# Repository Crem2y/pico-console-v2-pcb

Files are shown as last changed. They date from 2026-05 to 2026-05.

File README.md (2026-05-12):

# Pico console V2 Board
- Tool : Kicad 9.0
# schematics
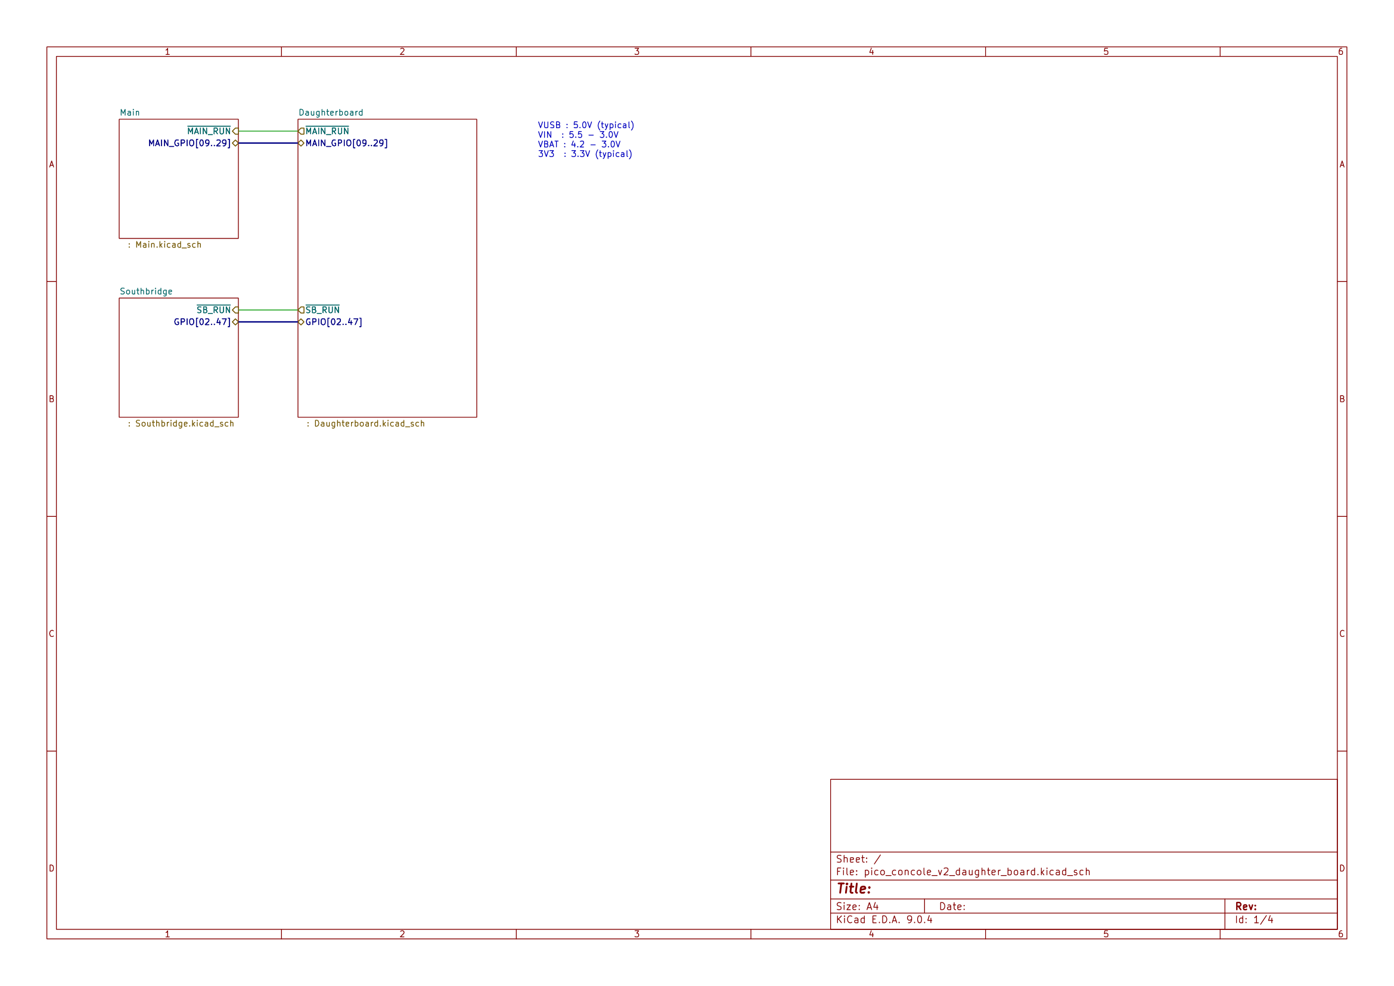
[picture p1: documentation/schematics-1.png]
schematics-1

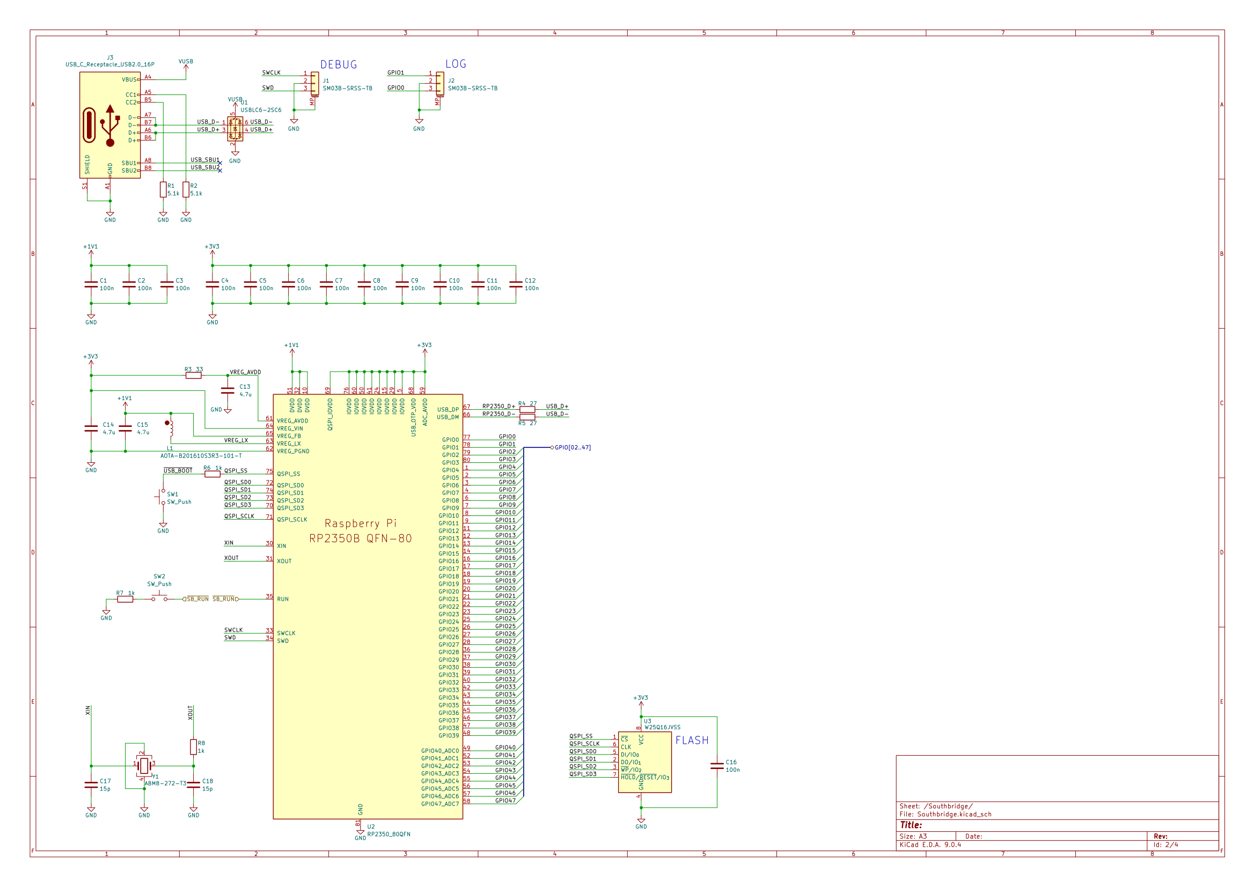
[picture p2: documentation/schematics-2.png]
schematics-2

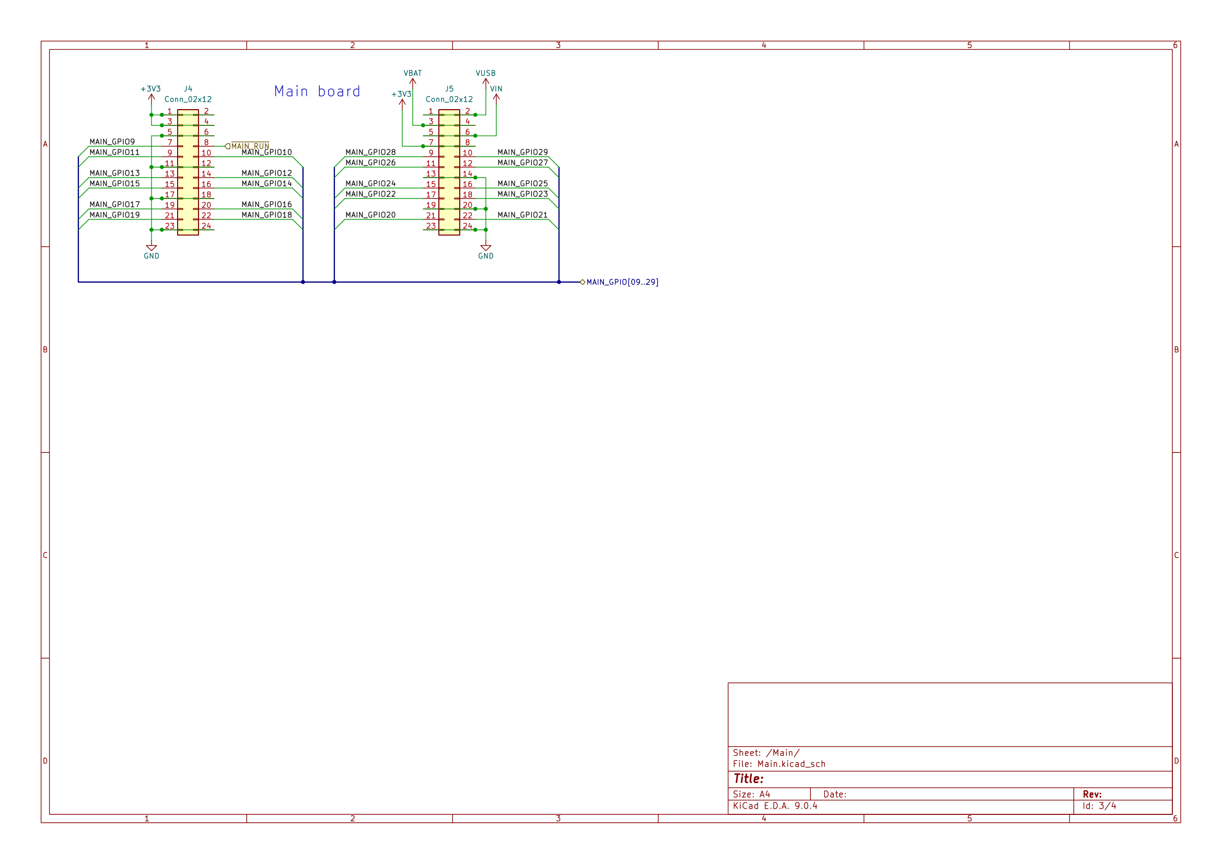
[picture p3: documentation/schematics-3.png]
schematics-3

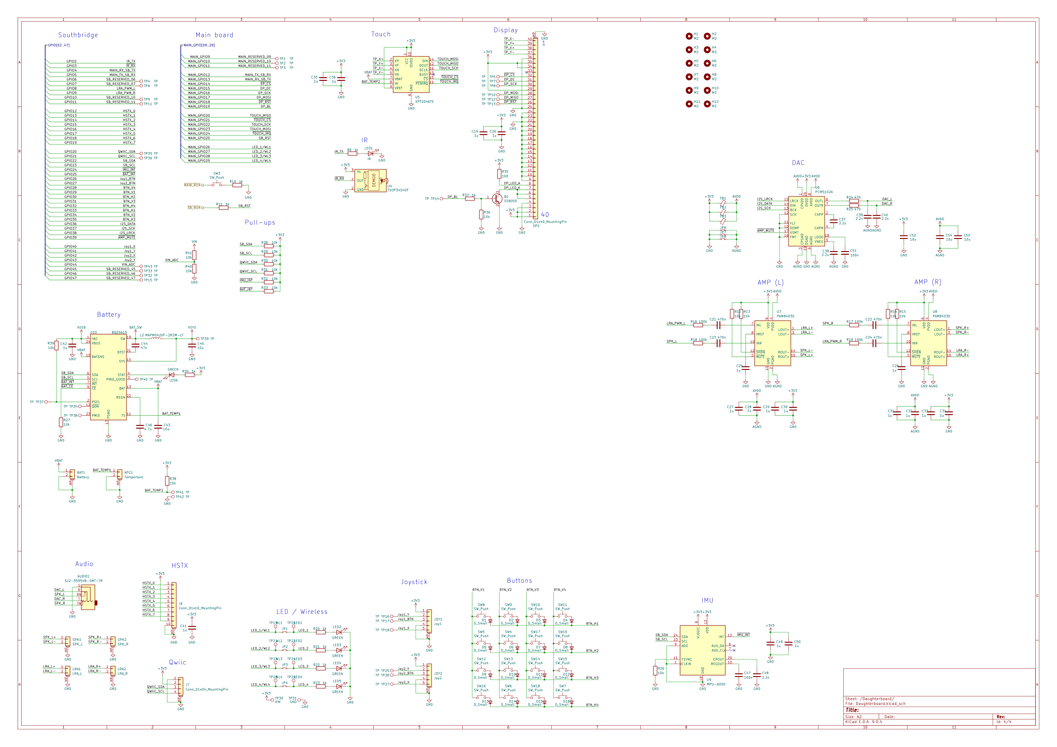
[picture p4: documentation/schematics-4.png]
schematics-4

# PCB
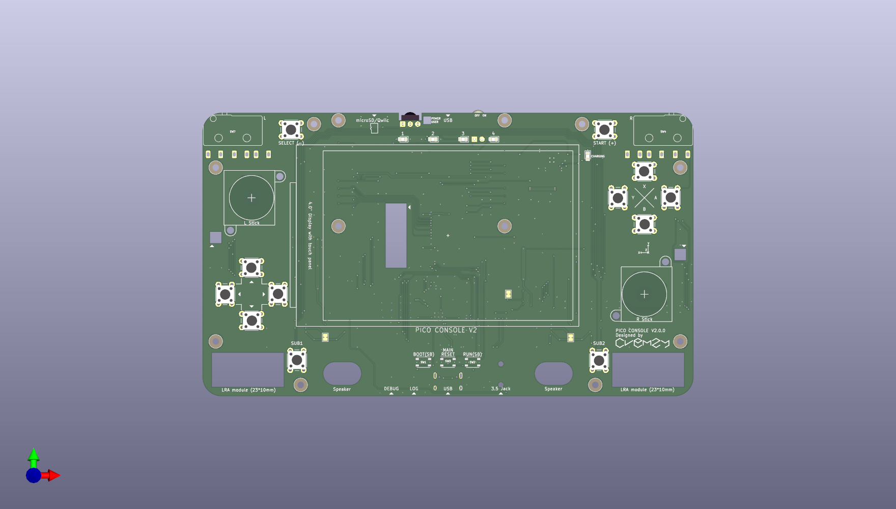
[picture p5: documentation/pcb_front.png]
pcb_front

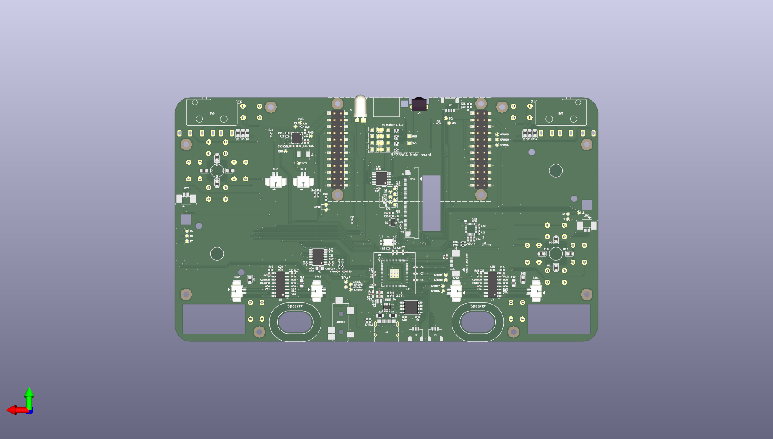
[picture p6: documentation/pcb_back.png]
pcb_back


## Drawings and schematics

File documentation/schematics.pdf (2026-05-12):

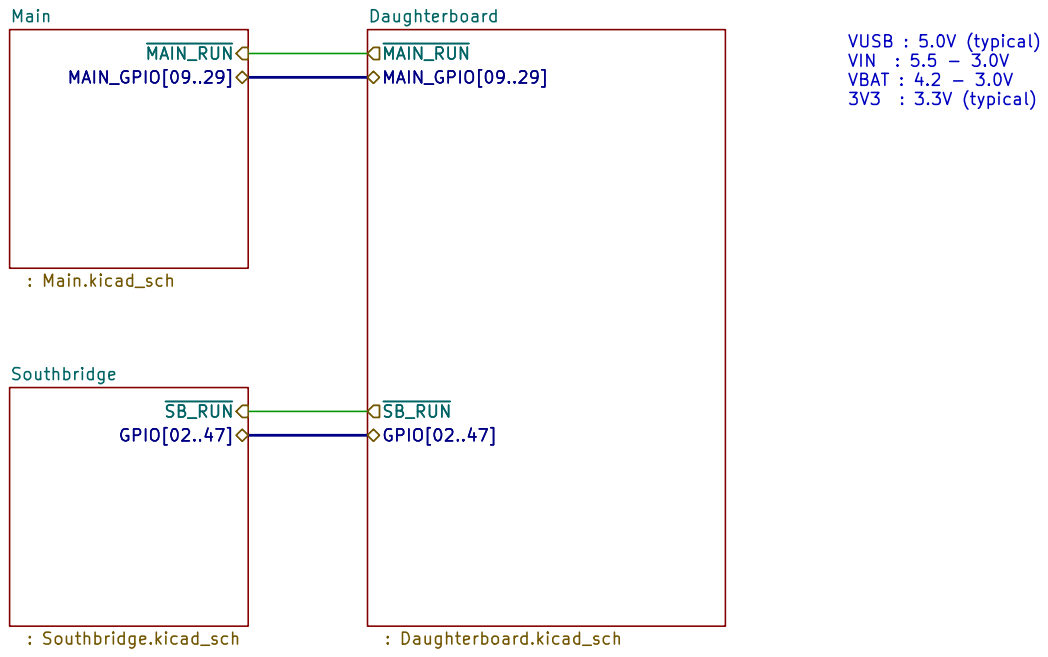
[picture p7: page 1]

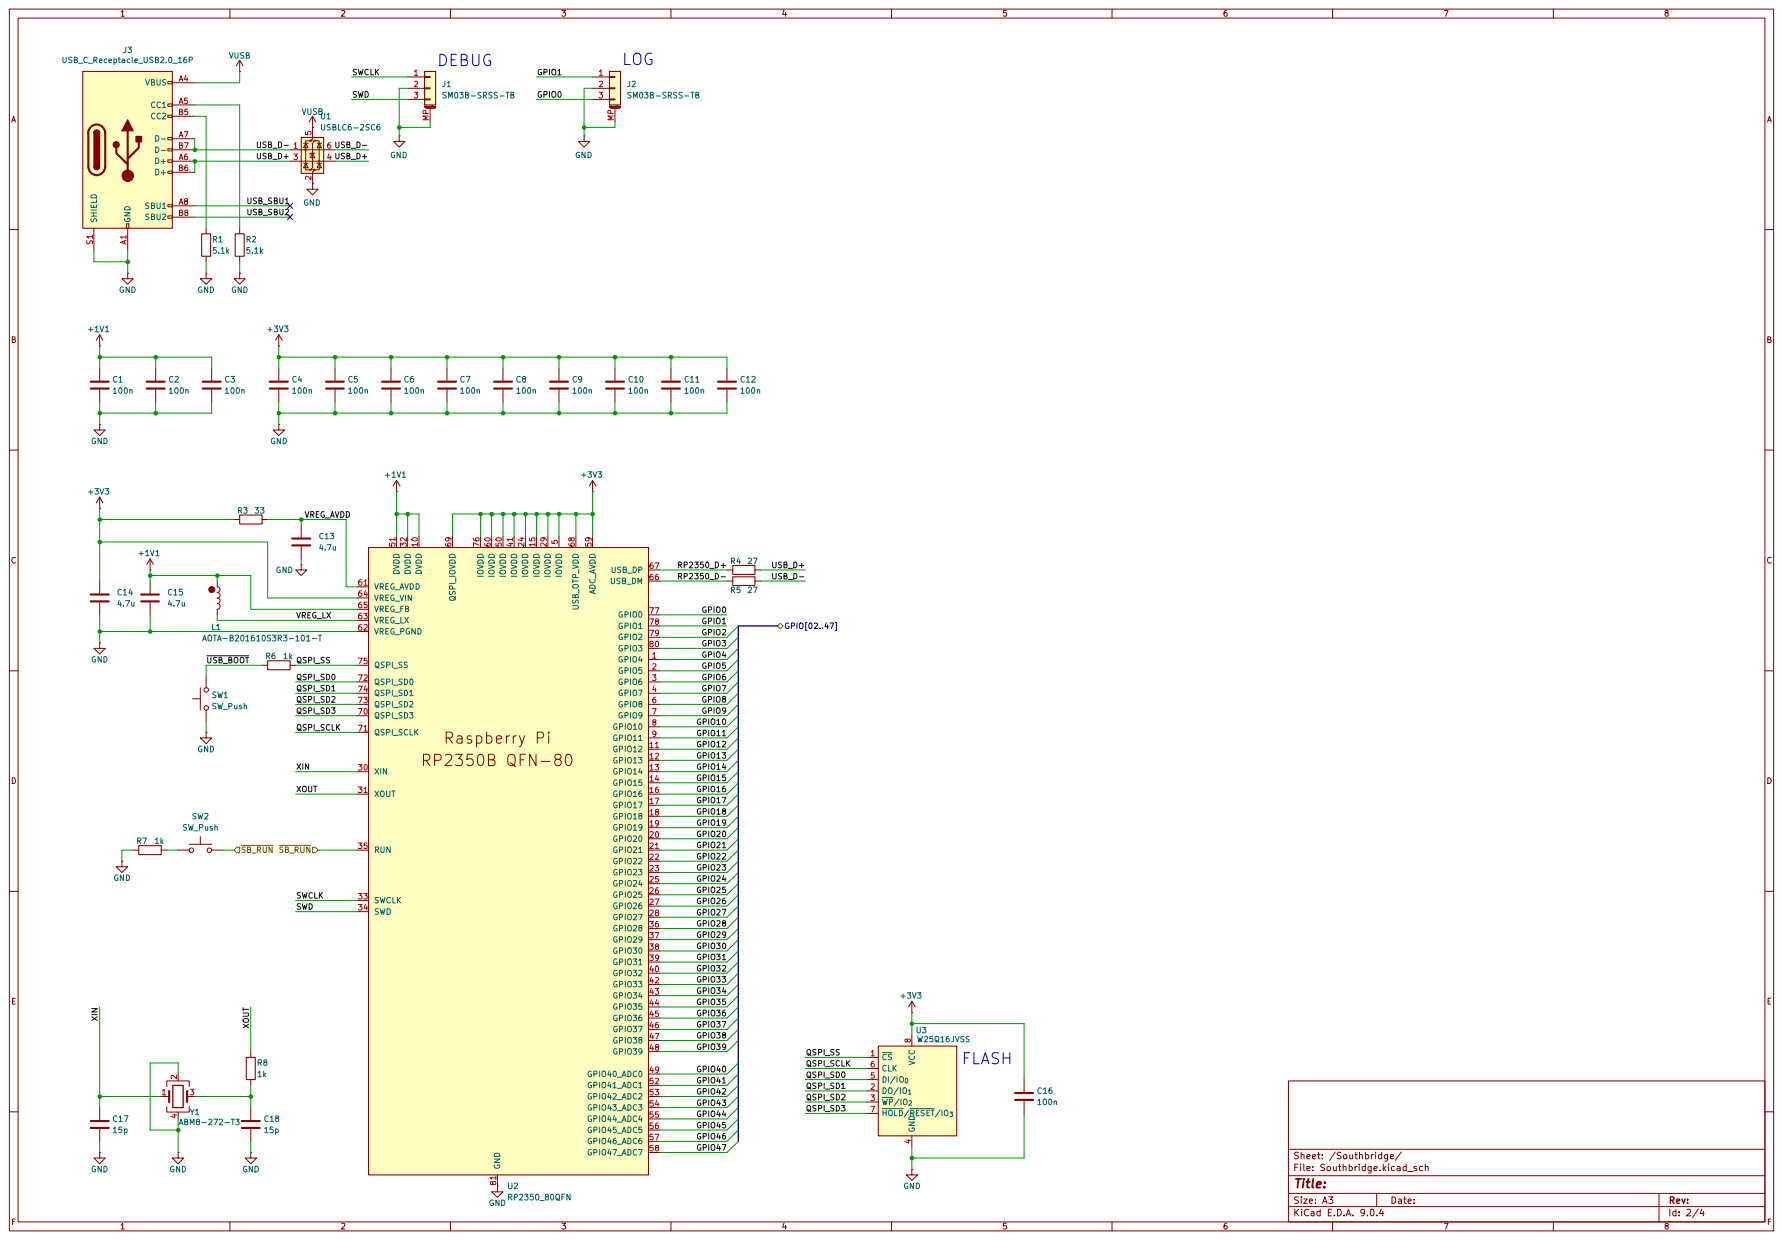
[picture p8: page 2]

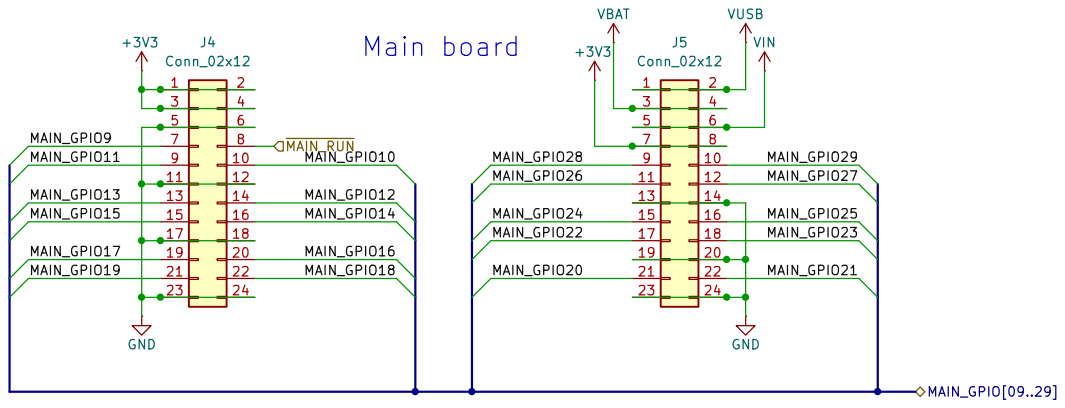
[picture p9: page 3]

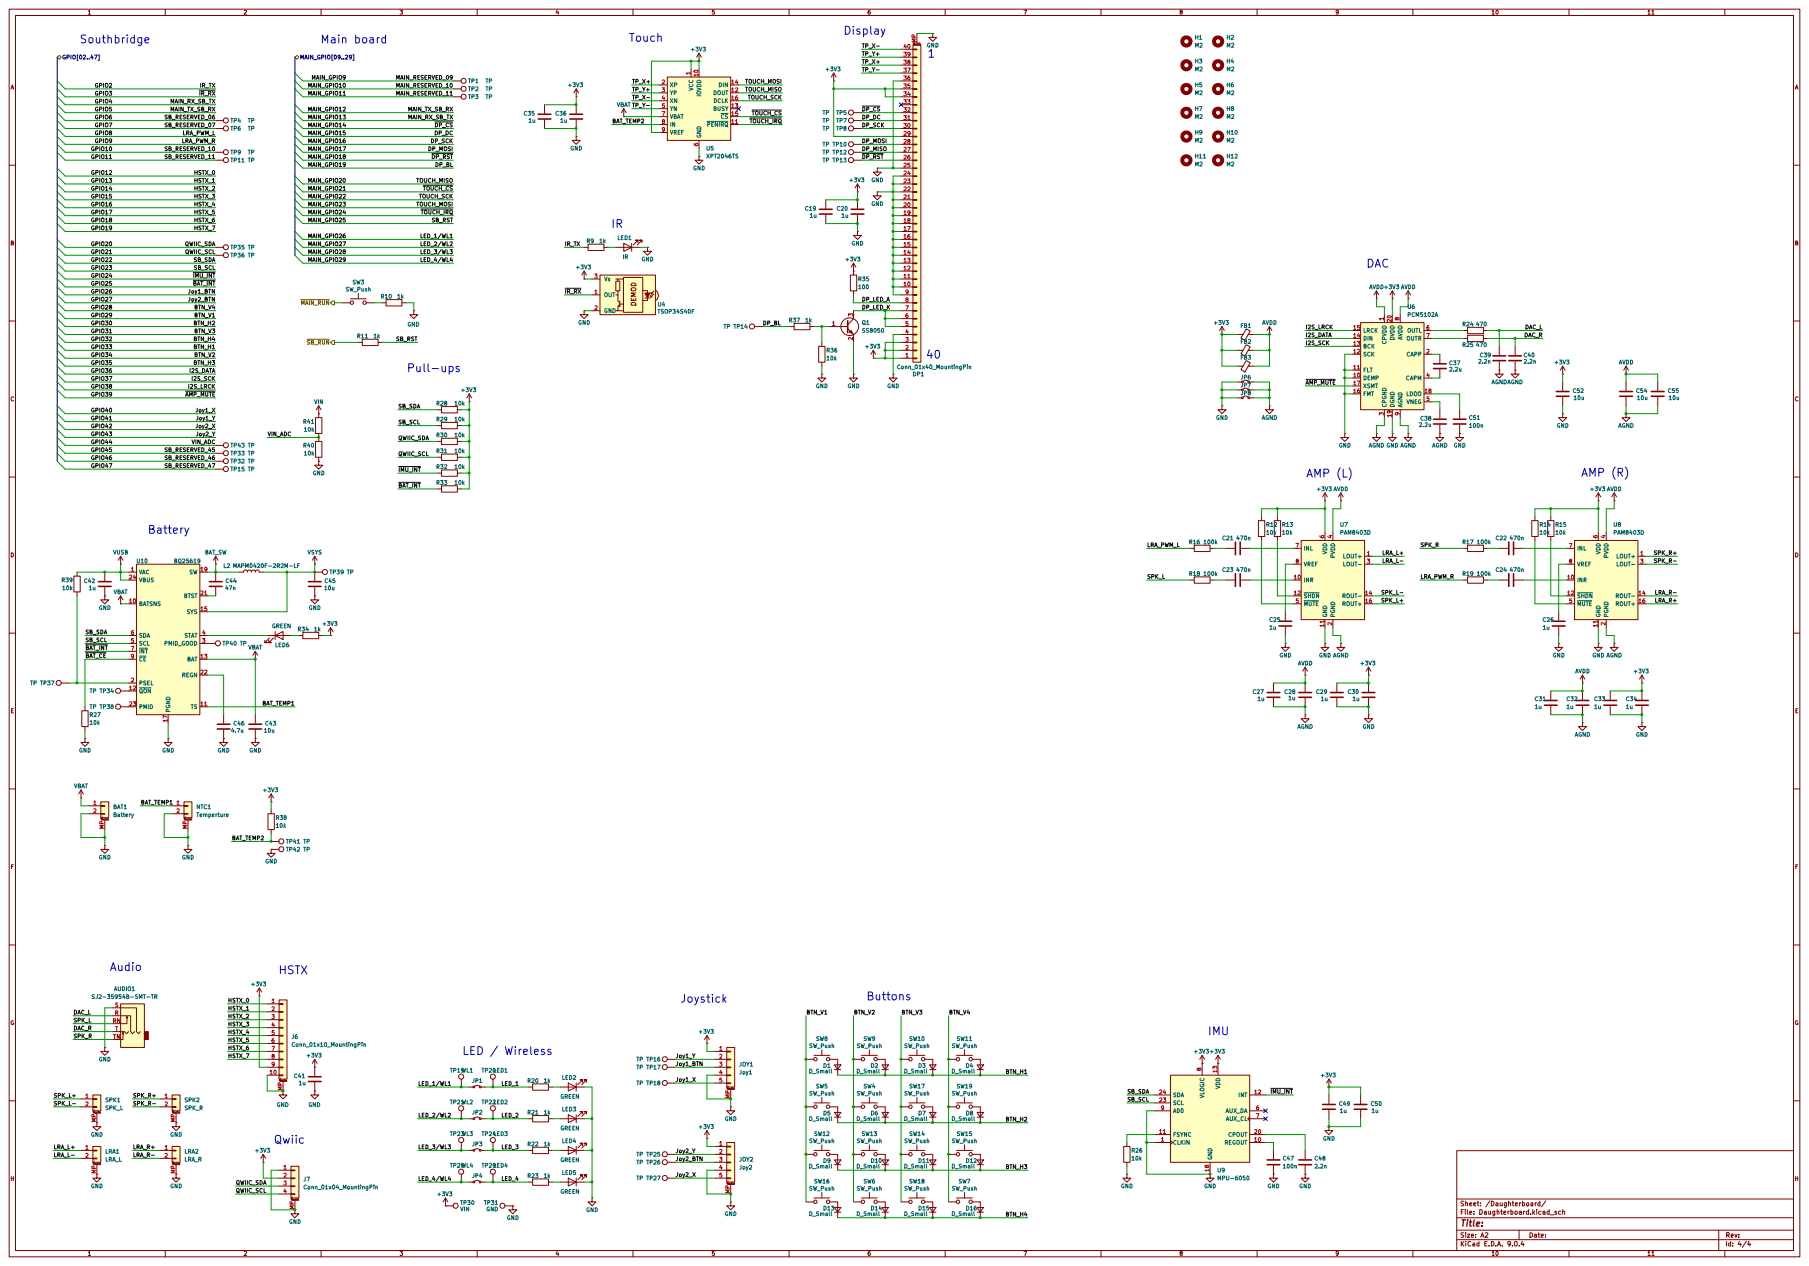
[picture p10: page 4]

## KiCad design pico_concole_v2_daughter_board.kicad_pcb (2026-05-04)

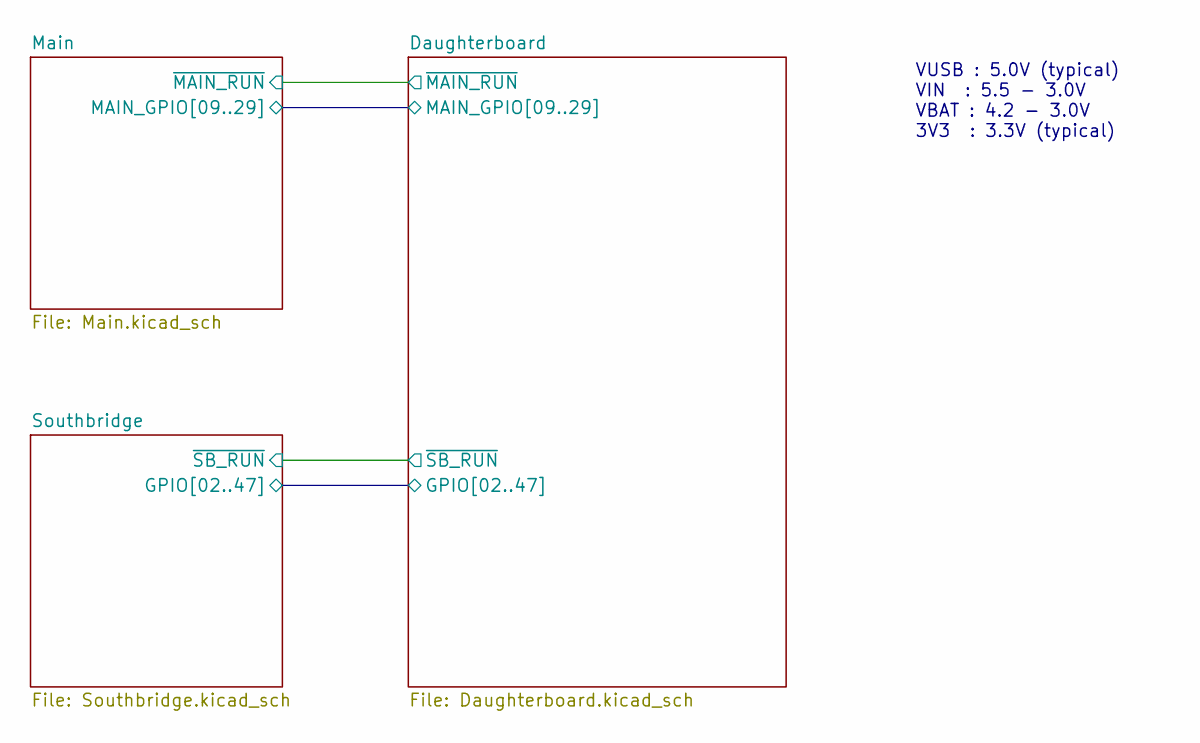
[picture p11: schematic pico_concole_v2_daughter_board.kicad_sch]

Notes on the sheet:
VUSB : 5.0V (typical) VIN : 5.5 - 3.0V VBAT : 4.2 - 3.0V 3V3 : 3.3V (typical)

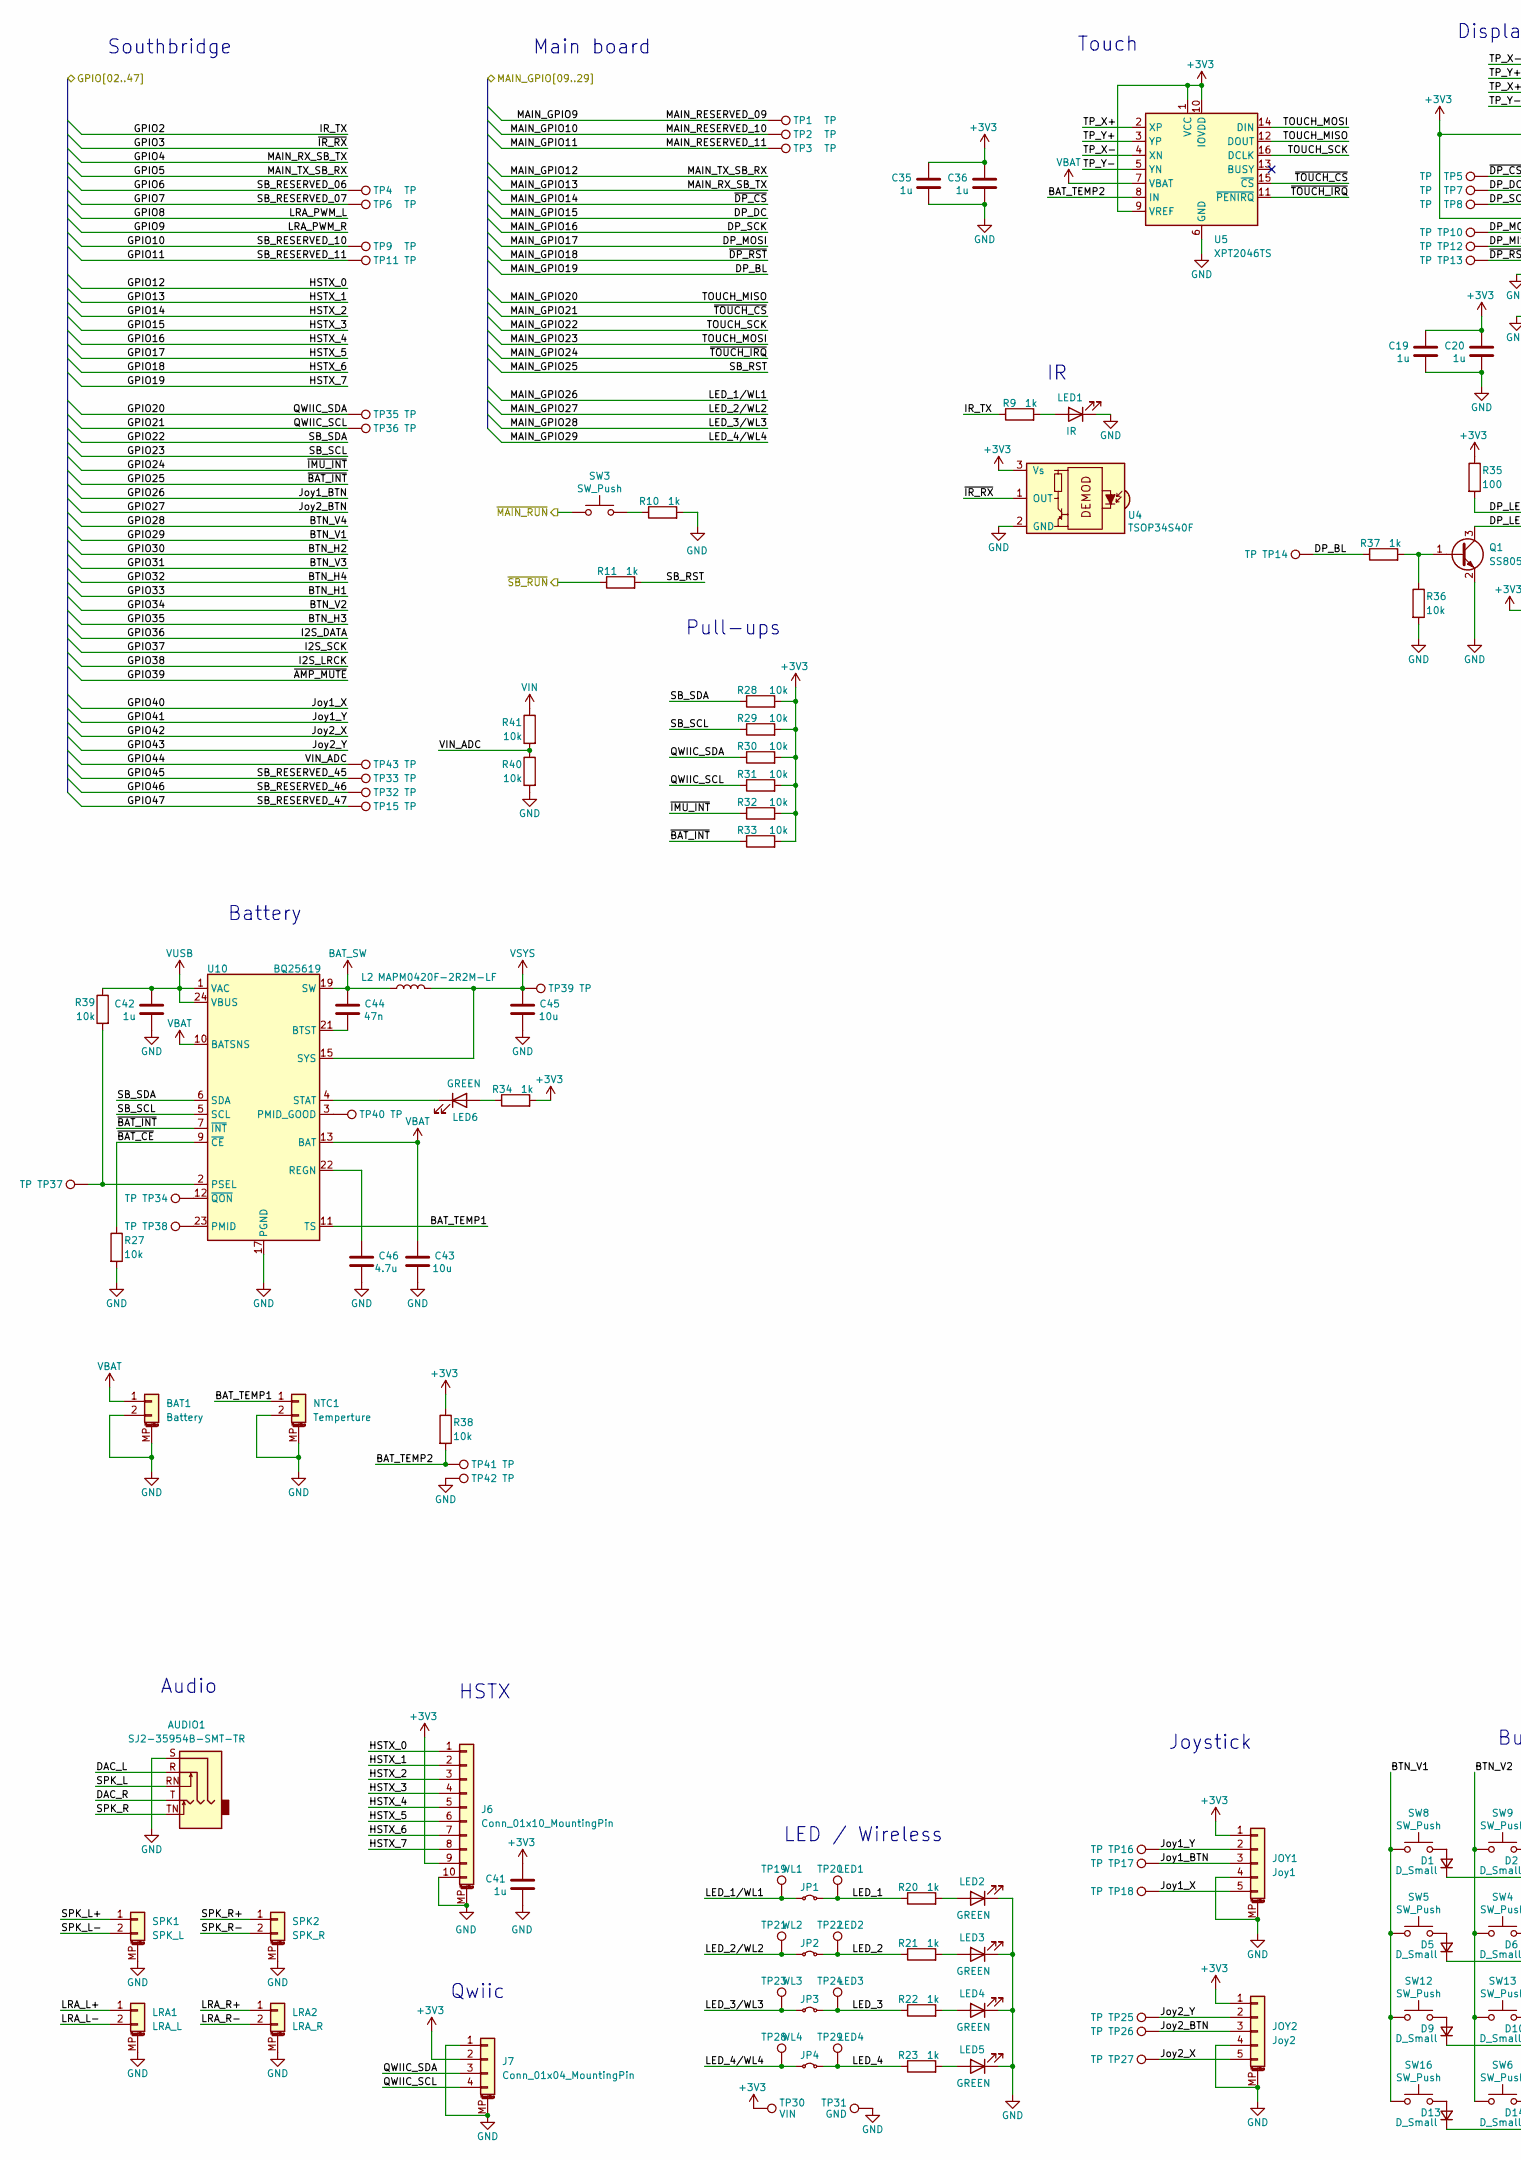
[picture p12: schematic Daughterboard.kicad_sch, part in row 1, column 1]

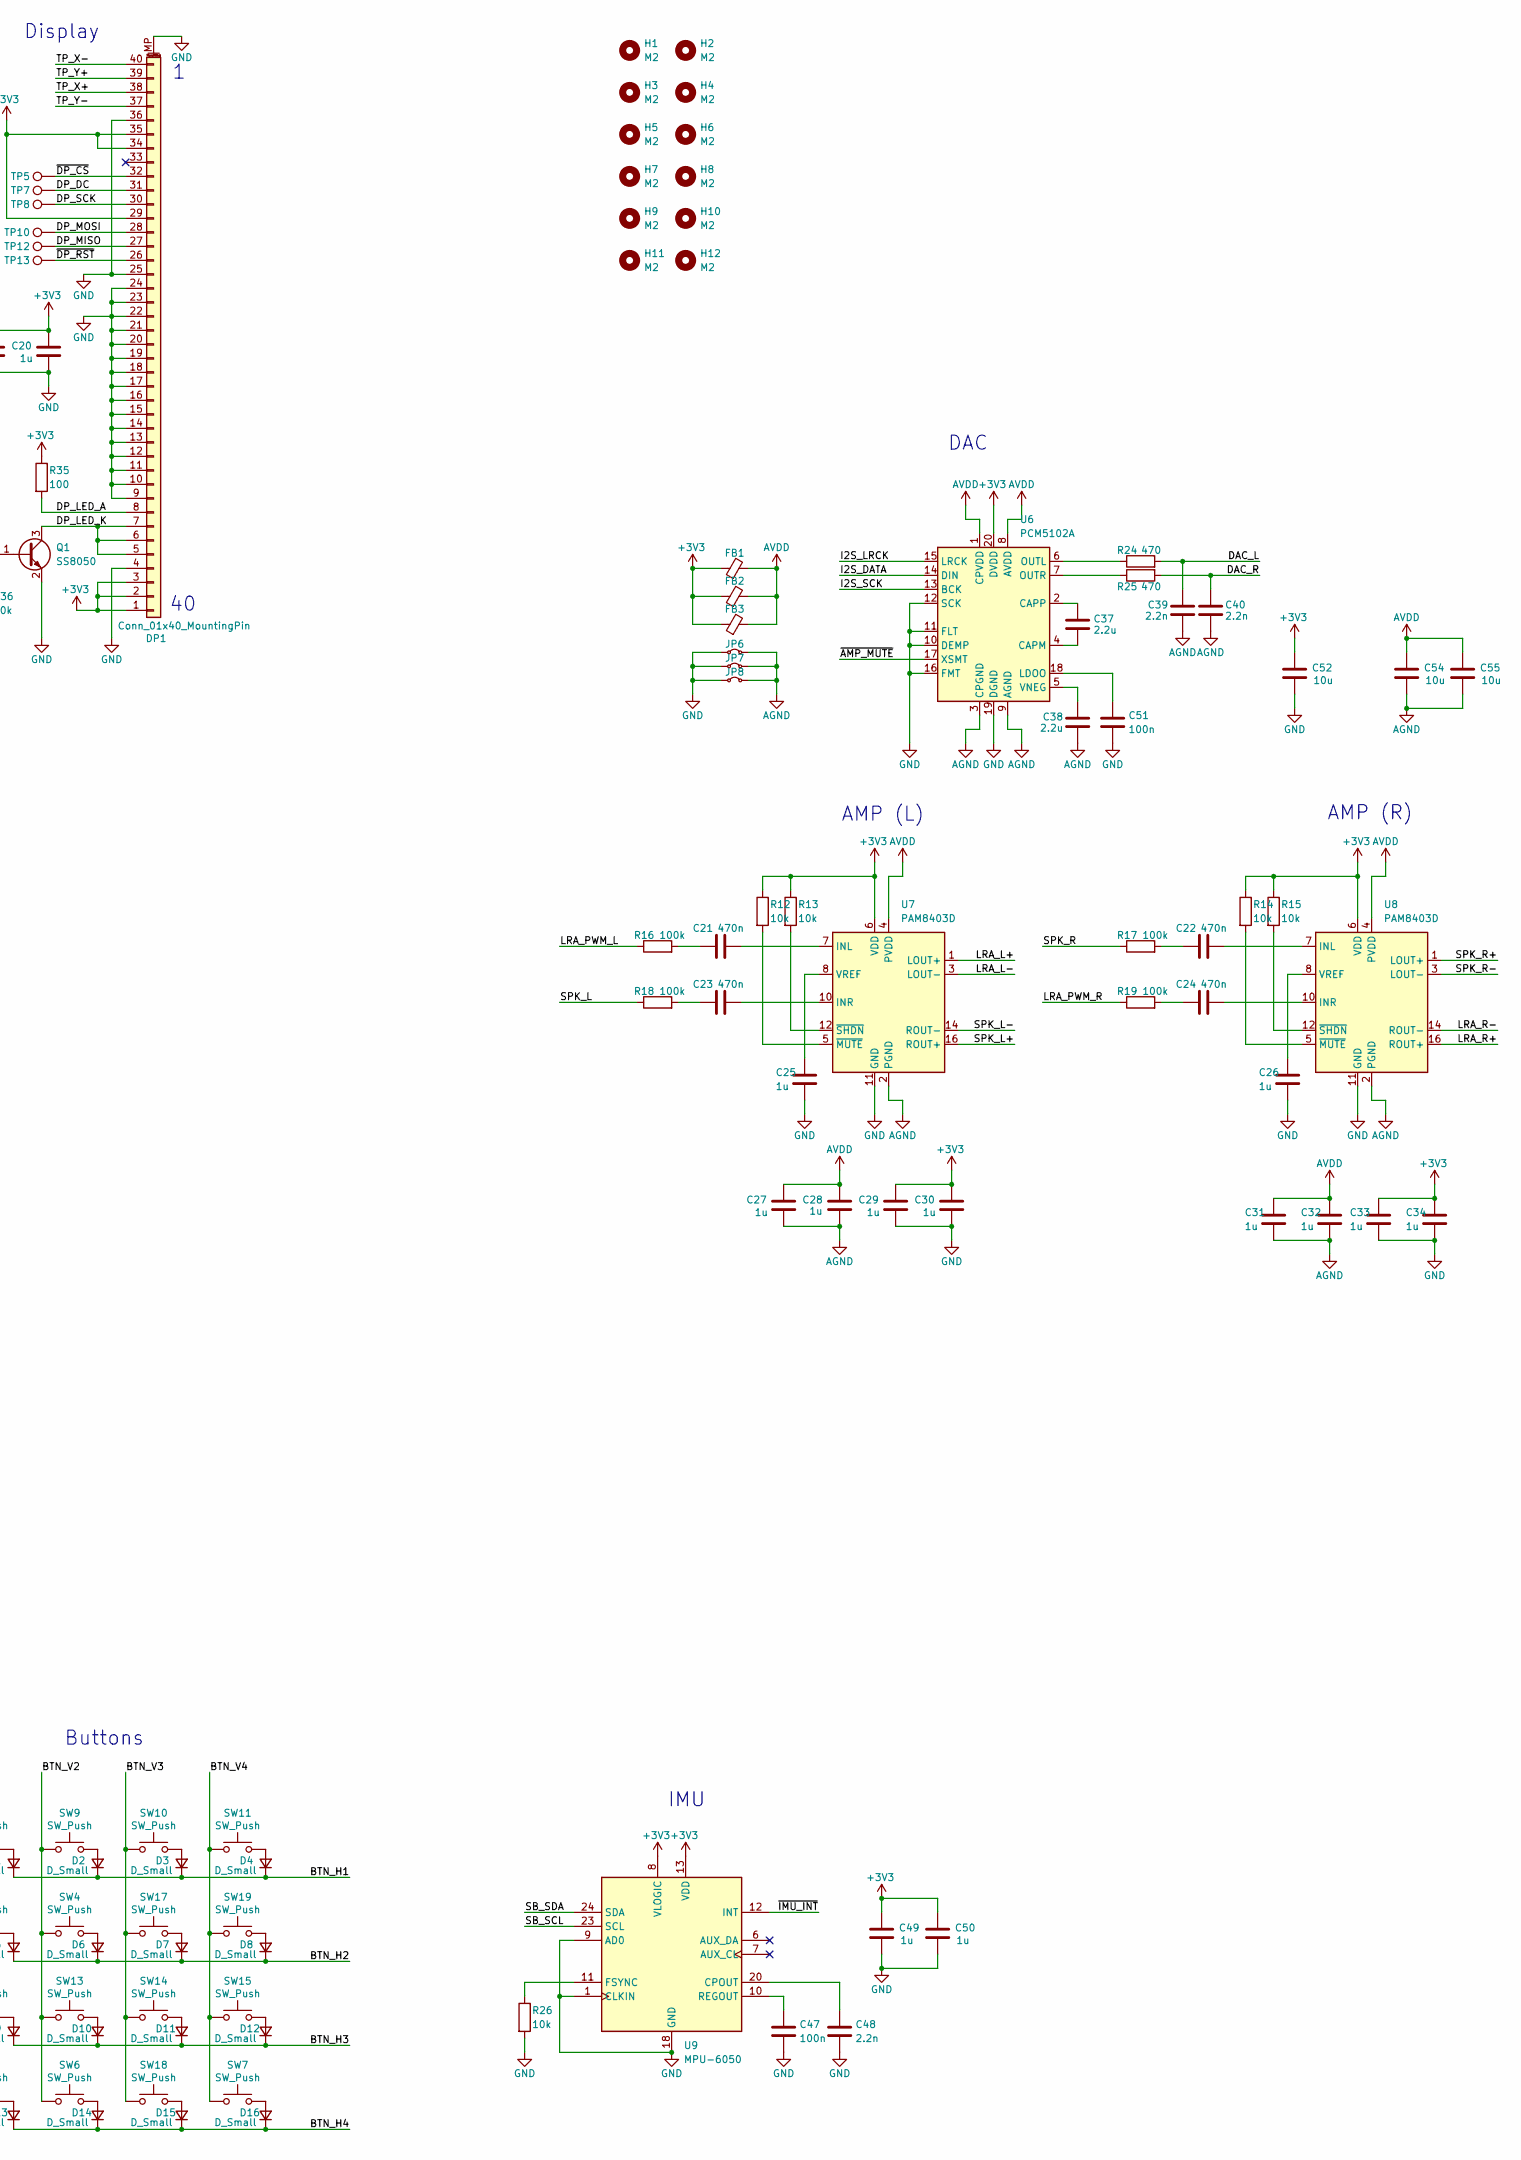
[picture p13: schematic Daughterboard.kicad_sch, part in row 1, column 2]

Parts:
AUDIO1: SJ2-35954B-SMT-TR; Jack_3.5mm_CUI_SJ2-3593D-SMT_Horizontal
BAT1: Battery; Molex_PicoBlade_53261-0271_1x02-1MP_P1.25mm_Horizontal; LCSC PN C177225
C19, C20, C25, C26, C27, C28, C29, C30, C31, C32, C33, C34, C35, C36, C41, C42, C49, C50: 1u; C_0402_1005Metric_Pad0.74x0.62mm_HandSolder
C21, C22, C23, C24: 470n; C_0402_1005Metric_Pad0.74x0.62mm_HandSolder
C37, C38: 2.2u; C_0402_1005Metric_Pad0.74x0.62mm_HandSolder
C39, C40, C48: 2.2n; C_0402_1005Metric_Pad0.74x0.62mm_HandSolder
C43, C45, C52, C54, C55: 10u; C_0402_1005Metric_Pad0.74x0.62mm_HandSolder
C44: 47n; C_0402_1005Metric_Pad0.74x0.62mm_HandSolder
C46: 4.7u; C_0402_1005Metric_Pad0.74x0.62mm_HandSolder
C47, C51: 100n; C_0402_1005Metric_Pad0.74x0.62mm_HandSolder
D1, D2, D3, D4, D5, D6, D7, D8, D9, D10, D11, D12, D13, D14, D15, D16: D_Small; D_0805_2012Metric_Pad1.15x1.40mm_HandSolder
DP1: Conn_01x40_MountingPin; Amphenol_F32Q-1A7x1-11040_1x40-1MP_P0.5mm_Horizontal
FB1, FB2, FB3: FerriteBead_Small; L_0805_2012Metric_Pad1.15x1.40mm_HandSolder
H1, H2, H3, H4, H5, H6, H7, H8, H9, H10, H11, H12: M2; MountingHole_2.2mm_M2
J6: Conn_01x10_MountingPin; TE_1-1734839-0_1x10-1MP_P0.5mm_Horizontal
J7: Conn_01x04_MountingPin; JST_SH_SM04B-SRSS-TB_1x04-1MP_P1.00mm_Horizontal; LCSC PN C160404
JOY1: Joy1; TE_0-1734839-5_1x05-1MP_P0.5mm_Horizontal
JOY2: Joy2; TE_0-1734839-5_1x05-1MP_P0.5mm_Horizontal
JP1, JP2, JP3, JP4: Jumper_2_Small_Bridged; SolderJumper-2_P1.3mm_Bridged_RoundedPad1.0x1.5mm
JP6, JP7, JP8: Jumper_2_Small_Bridged; SolderJumper-2_P1.3mm_Bridged_Pad1.0x1.5mm
L2: MAPM0420F-2R2M-LF; Inductor_SMD_L_4.9x4.4_H2
LED1: IR; LED_D5.0mm_Horizontal_O1.27mm_Z3.0mm_Clear
LED2, LED3, LED4, LED5, LED6: GREEN; LED_0805_2012Metric_Pad1.15x1.40mm_HandSolder
LRA1: LRA_L; Molex_PicoBlade_53261-0271_1x02-1MP_P1.25mm_Horizontal; LCSC PN C177225
LRA2: LRA_R; Molex_PicoBlade_53261-0271_1x02-1MP_P1.25mm_Horizontal; LCSC PN C177225
NTC1: Temperture; Molex_PicoBlade_53261-0271_1x02-1MP_P1.25mm_Horizontal; LCSC PN C177225
Q1: SS8050; SOT-23
R9, R10, R11, R20, R21, R22, R23, R34, R37: 1k; R_0402_1005Metric_Pad0.72x0.64mm_HandSolder
R12, R13, R14, R15, R26, R27, R28, R29, R30, R31, R32, R33, R36, R38, R39, R40, R41: 10k; R_0402_1005Metric_Pad0.72x0.64mm_HandSolder
R16, R17, R18, R19: 100k; R_0402_1005Metric_Pad0.72x0.64mm_HandSolder
R24, R25: 470; R_0402_1005Metric_Pad0.72x0.64mm_HandSolder
R35: 100; R_0402_1005Metric_Pad0.72x0.64mm_HandSolder
SPK1: SPK_L; Molex_PicoBlade_53261-0271_1x02-1MP_P1.25mm_Horizontal; LCSC PN C177225
SPK2: SPK_R; Molex_PicoBlade_53261-0271_1x02-1MP_P1.25mm_Horizontal; LCSC PN C177225
SW3: SW_Push; SW_Push_1P1T_NO_Vertical_Wuerth_434133025816
SW4, SW6: SW_Push; SM-05H-0xC-Zippy
SW5, SW7: SW_Push; SM-05H-0xD-Zippy
SW8, SW9, SW10, SW11, SW12, SW13, SW14, SW15, SW16, SW17, SW18, SW19: SW_Push; SW_PUSH_6mm_H7.3mm
TP1, TP2, TP3, TP4, TP5, TP6, TP7, TP8, TP9, TP10, TP11, TP12, TP13, TP14, TP15, TP16, TP17, TP18, TP25, TP26, TP27, TP32, TP33, TP34, TP35, TP36, TP37, TP38, TP39, TP40, TP41, TP42, TP43: TP; TestPoint_Pad_D1.0mm
TP19: WL1; TestPoint_Pad_1.0x1.0mm
TP20: LED1; TestPoint_Pad_1.0x1.0mm
TP21: WL2; TestPoint_Pad_1.0x1.0mm
TP22: LED2; TestPoint_Pad_1.0x1.0mm
TP23: WL3; TestPoint_Pad_1.0x1.0mm
TP24: LED3; TestPoint_Pad_1.0x1.0mm
TP28: WL4; TestPoint_Pad_1.0x1.0mm
TP29: LED4; TestPoint_Pad_1.0x1.0mm
TP30: VIN; TestPoint_Pad_1.0x1.0mm
TP31: GND; TestPoint_Pad_1.0x1.0mm
U4: TSOP34S40F; Vishay_MOLD-3Pin
U5: XPT2046TS; TSSOP-16_4.4x5mm_P0.65mm
U6: PCM5102A; TSSOP-20_4.4x6.5mm_P0.65mm
U7, U8: PAM8403D; SOIC-16_3.9x9.9mm_P1.27mm
U9: MPU-6050; InvenSense_QFN-24_4x4mm_P0.5mm
U10: BQ25619; Texas_RTW_WQFN-24-1EP_4x4mm_P0.5mm_EP2.7x2.7mm

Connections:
+3V3: C19.1, C20.1, C29.1, C30.1, C33.1, C34.1, C35.1, C36.1, C41.1, C49.1, C50.1, C52.1, DP1.1, DP1.2, DP1.3, DP1.29, DP1.34, DP1.35, FB1.1, FB2.1, FB3.1, J6.9, J7.2, JOY1.1, JOY2.1, R12.1, R13.1, R14.1, R15.1, R28.2, R29.2, R30.2, R31.2, R32.2, R33.2, R34.2, R35.1, R38.1, TP30.1, U4.3 (Vs), U5.1 (VCC), U5.9 (VREF), U5.10 (IOVDD), U6.20 (DVDD), U7.6 (VDD), U8.6 (VDD), U9.8 (VLOGIC), U9.13 (VDD); also elsewhere on the board
/Daughterboard/BAT_TEMP1: NTC1.1, U10.11 (TS)
/Daughterboard/BAT_TEMP2: R38.2, TP41.1, U5.8 (IN)
/Daughterboard/DAC_L: AUDIO1.R, C39.2, R24.2
/Daughterboard/DAC_R: AUDIO1.T, C40.2, R25.2
/Daughterboard/DP_LED_A: DP1.8, R35.2
/Daughterboard/DP_LED_K: DP1.5, DP1.6, DP1.7, Q1.3 (C)
/Daughterboard/DP_MISO: DP1.27, TP12.1
/Daughterboard/GPIO2: R9.1; also elsewhere on the board
/Daughterboard/GPIO3: U4.1 (OUT); also elsewhere on the board
/Daughterboard/GPIO6: TP4.1; also elsewhere on the board
/Daughterboard/GPIO7: TP6.1; also elsewhere on the board
/Daughterboard/GPIO8: R16.1; also elsewhere on the board
/Daughterboard/GPIO9: R19.1; also elsewhere on the board
/Daughterboard/GPIO10: TP9.1; also elsewhere on the board
/Daughterboard/GPIO11: TP11.1; also elsewhere on the board
/Daughterboard/GPIO12: J6.1; also elsewhere on the board
/Daughterboard/GPIO13: J6.2; also elsewhere on the board
/Daughterboard/GPIO14: J6.3; also elsewhere on the board
/Daughterboard/GPIO15: J6.4; also elsewhere on the board
/Daughterboard/GPIO16: J6.5; also elsewhere on the board
/Daughterboard/GPIO17: J6.6; also elsewhere on the board
/Daughterboard/GPIO18: J6.7; also elsewhere on the board
/Daughterboard/GPIO19: J6.8; also elsewhere on the board
/Daughterboard/GPIO20: J7.3, R30.1, TP35.1; also elsewhere on the board
/Daughterboard/GPIO21: J7.4, R31.1, TP36.1; also elsewhere on the board
/Daughterboard/GPIO22: R28.1, U9.24 (SDA), U10.6 (SDA); also elsewhere on the board
/Daughterboard/GPIO23: R29.1, U9.23 (SCL), U10.5 (SCL); also elsewhere on the board
/Daughterboard/GPIO24: R32.1, U9.12 (INT); also elsewhere on the board
/Daughterboard/GPIO25: R33.1, U10.7 (~INT); also elsewhere on the board
/Daughterboard/GPIO26: JOY1.3, TP17.1; also elsewhere on the board
/Daughterboard/GPIO27: JOY2.3, TP26.1; also elsewhere on the board
/Daughterboard/GPIO28: SW7.1, SW11.1, SW15.1, SW19.1; also elsewhere on the board
/Daughterboard/GPIO29: SW5.1, SW8.1, SW12.1, SW16.1; also elsewhere on the board
/Daughterboard/GPIO30: D5.1 (K), D6.1 (K), D7.1 (K), D8.1 (K); also elsewhere on the board
/Daughterboard/GPIO31: SW10.1, SW14.1, SW17.1, SW18.1; also elsewhere on the board
/Daughterboard/GPIO32: D13.1 (K), D14.1 (K), D15.1 (K), D16.1 (K); also elsewhere on the board
/Daughterboard/GPIO33: D1.1 (K), D2.1 (K), D3.1 (K), D4.1 (K); also elsewhere on the board
/Daughterboard/GPIO34: SW4.1, SW6.1, SW9.1, SW13.1; also elsewhere on the board
/Daughterboard/GPIO35: D9.1 (K), D10.1 (K), D11.1 (K), D12.1 (K); also elsewhere on the board
/Daughterboard/GPIO36: U6.14 (DIN); also elsewhere on the board
/Daughterboard/GPIO37: U6.13 (BCK); also elsewhere on the board
/Daughterboard/GPIO38: U6.15 (LRCK); also elsewhere on the board
/Daughterboard/GPIO39: U6.17 (XSMT); also elsewhere on the board
/Daughterboard/GPIO40: JOY1.5, TP18.1; also elsewhere on the board
/Daughterboard/GPIO41: JOY1.2, TP16.1; also elsewhere on the board
/Daughterboard/GPIO42: JOY2.5, TP27.1; also elsewhere on the board
/Daughterboard/GPIO43: JOY2.2, TP25.1; also elsewhere on the board
/Daughterboard/GPIO44: R40.1, R41.2, TP43.1; also elsewhere on the board
/Daughterboard/GPIO45: TP33.1; also elsewhere on the board
/Daughterboard/GPIO46: TP32.1; also elsewhere on the board
/Daughterboard/GPIO47: TP15.1; also elsewhere on the board
/Daughterboard/LED_1: JP1.2 (B), R20.1, TP20.1
/Daughterboard/LED_2: JP2.2 (B), R21.1, TP22.1
/Daughterboard/LED_3: JP3.2 (B), R22.1, TP24.1
/Daughterboard/LED_4: JP4.2 (B), R23.1, TP29.1
/Daughterboard/LRA_L+: LRA1.1, U7.1 (LOUT+)
/Daughterboard/LRA_L-: LRA1.2, U7.3 (LOUT-)
/Daughterboard/LRA_R+: LRA2.1, U8.16 (ROUT+)
/Daughterboard/LRA_R-: LRA2.2, U8.14 (ROUT-)
/Daughterboard/MAIN_GPIO9: TP1.1; also elsewhere on the board
/Daughterboard/MAIN_GPIO10: TP2.1; also elsewhere on the board
/Daughterboard/MAIN_GPIO11: TP3.1; also elsewhere on the board
/Daughterboard/MAIN_GPIO14: DP1.32, TP5.1; also elsewhere on the board
/Daughterboard/MAIN_GPIO15: DP1.31, TP7.1; also elsewhere on the board
/Daughterboard/MAIN_GPIO16: DP1.30, TP8.1; also elsewhere on the board
/Daughterboard/MAIN_GPIO17: DP1.28, TP10.1; also elsewhere on the board
/Daughterboard/MAIN_GPIO18: DP1.26, TP13.1; also elsewhere on the board
/Daughterboard/MAIN_GPIO19: R37.1, TP14.1; also elsewhere on the board
/Daughterboard/MAIN_GPIO20: U5.12 (DOUT); also elsewhere on the board
/Daughterboard/MAIN_GPIO21: U5.15 (~CS); also elsewhere on the board
/Daughterboard/MAIN_GPIO22: U5.16 (DCLK); also elsewhere on the board
/Daughterboard/MAIN_GPIO23: U5.14 (DIN); also elsewhere on the board
/Daughterboard/MAIN_GPIO24: U5.11 (~PENIRQ); also elsewhere on the board
/Daughterboard/MAIN_GPIO25: R11.2; also elsewhere on the board
/Daughterboard/MAIN_GPIO26: JP1.1 (A), TP19.1; also elsewhere on the board
/Daughterboard/MAIN_GPIO27: JP2.1 (A), TP21.1; also elsewhere on the board
/Daughterboard/MAIN_GPIO28: JP3.1 (A), TP23.1; also elsewhere on the board
/Daughterboard/MAIN_GPIO29: JP4.1 (A), TP28.1; also elsewhere on the board
/Daughterboard/SPK_L: AUDIO1.RN, R18.1
/Daughterboard/SPK_L+: SPK1.1, U7.16 (ROUT+)
/Daughterboard/SPK_L-: SPK1.2, U7.14 (ROUT-)
/Daughterboard/SPK_R: AUDIO1.TN, R17.1
/Daughterboard/SPK_R+: SPK2.1, U8.1 (LOUT+)
/Daughterboard/SPK_R-: SPK2.2, U8.3 (LOUT-)
/Daughterboard/TP_X+: DP1.38, U5.2 (XP)
/Daughterboard/TP_X-: DP1.40, U5.4 (XN)
/Daughterboard/TP_Y+: DP1.39, U5.3 (YP)
/Daughterboard/TP_Y-: DP1.37, U5.5 (YN)
/Daughterboard/~BAT_CE: R27.1, U10.9 (~CE)
/Daughterboard/~MAIN_RUN: SW3.1; also elsewhere on the board
/Daughterboard/~SB_RUN: R11.1; also elsewhere on the board
AGND: C27.2, C28.2, C31.2, C32.2, C38.2, C39.1, C40.1, C54.2, C55.2, JP6.2 (B), JP7.2 (B), JP8.2 (B), U6.3 (CPGND), U6.9 (AGND), U7.2 (PGND), U7.15 (PGND), U8.2 (PGND), U8.15 (PGND)
AVDD: C27.1, C28.1, C31.1, C32.1, C54.1, C55.1, FB1.2, FB2.2, FB3.2, U6.1 (CPVDD), U6.8 (AVDD), U7.4 (PVDD), U7.13 (PVDD), U8.4 (PVDD), U8.13 (PVDD)
BAT_SW: C44.1, L2.1, U10.19 (SW), U10.20 (SW)
GND: AUDIO1.S, BAT1.2, BAT1.MP (MountPin), C19.2, C20.2, C25.2, C26.2, C29.2, C30.2, C33.2, C34.2, C35.2, C36.2, C41.2, C42.2, C43.2, C45.2, C46.2, C47.2, C48.2, C49.2, C50.2, C51.2, C52.2, DP1.4, DP1.9, DP1.10, DP1.11, DP1.12, DP1.13, DP1.14, DP1.15, DP1.16, DP1.17, DP1.18, DP1.19, DP1.20, DP1.21, DP1.22, DP1.23, DP1.24, DP1.25, DP1.36, DP1.MP (MountPin), J6.10, J6.MP (MountPin), J7.1, J7.MP (MountPin), JOY1.4, JOY1.MP (MountPin), JOY2.4, JOY2.MP (MountPin), JP6.1 (A), JP7.1 (A), JP8.1 (A), LED1.1 (K), LED2.1 (K), LED3.1 (K), LED4.1 (K), LED5.1 (K), LRA1.MP (MountPin), LRA2.MP (MountPin), NTC1.2, NTC1.MP (MountPin), Q1.2 (E), R10.2, R26.2, R27.2, R36.2, R40.2, SPK1.MP (MountPin), SPK2.MP (MountPin), TP31.1, TP42.1, U4.2 (GND), U5.6 (GND), U6.10 (DEMP), U6.11 (FLT), U6.12 (SCK), U6.16 (FMT), U6.19 (DGND), U7.11 (GND), U8.11 (GND), U9.1 (CLKIN), U9.9 (AD0), U9.18 (GND), U10.17 (PGND), U10.18 (PGND), U10.25 (PGND); also elsewhere on the board
unnamed: C21.1, R16.2
unnamed: C22.1, R17.2
unnamed: C23.1, R18.2
unnamed: C24.1, R19.2
unnamed: D1.2 (A), SW8.2
unnamed: D2.2 (A), SW9.2
unnamed: D3.2 (A), SW10.2
unnamed: D4.2 (A), SW11.2
unnamed: D5.2 (A), SW5.2
unnamed: D6.2 (A), SW4.2
unnamed: D7.2 (A), SW17.2
unnamed: D8.2 (A), SW19.2
unnamed: D9.2 (A), SW12.2
unnamed: D10.2 (A), SW13.2
unnamed: D11.2 (A), SW14.2
unnamed: D12.2 (A), SW15.2
unnamed: D13.2 (A), SW16.2
unnamed: D14.2 (A), SW6.2
unnamed: D15.2 (A), SW18.2
unnamed: D16.2 (A), SW7.2
unnamed: LED1.2 (A), R9.2
unnamed: LED2.2 (A), R20.2
unnamed: LED3.2 (A), R21.2
unnamed: LED4.2 (A), R22.2
unnamed: LED5.2 (A), R23.2
unnamed: LED6.2 (A), R34.1
unnamed: LED6.1 (K), U10.4 (STAT)
unnamed: Q1.1 (B), R36.1, R37.2
unnamed: R10.1, SW3.2
unnamed: C37.2, U6.4 (CAPM)
unnamed: C37.1, U6.2 (CAPP)
unnamed: C51.1, U6.18 (LDOO)
unnamed: R24.1, U6.6 (OUTL)
unnamed: R25.1, U6.7 (OUTR)
unnamed: C38.1, U6.5 (VNEG)
unnamed: C21.2, U7.7 (INL)
unnamed: C23.2, U7.10 (INR)
unnamed: C25.1, U7.8 (VREF)
unnamed: R12.2, U7.5 (~MUTE)
unnamed: R13.2, U7.12 (~SHDN)
unnamed: C22.2, U8.7 (INL)
unnamed: C24.2, U8.10 (INR)
unnamed: C26.1, U8.8 (VREF)
unnamed: R14.2, U8.5 (~MUTE)
unnamed: R15.2, U8.12 (~SHDN)
unnamed: C48.1, U9.20 (CPOUT)
unnamed: R26.1, U9.11 (FSYNC)
unnamed: C47.1, U9.10 (REGOUT)
unnamed: C44.2, U10.21 (BTST)
unnamed: TP38.1, U10.23 (PMID)
unnamed: TP40.1, U10.3 (PMID_GOOD)
unnamed: R39.2, TP37.1, U10.2 (PSEL)
unnamed: C46.1, U10.22 (REGN)
unnamed: TP34.1, U10.12 (~QON)
VBAT: BAT1.1, C43.1, U5.7 (VBAT), U10.10 (BATSNS), U10.13 (BAT), U10.14 (BAT); also elsewhere on the board
VIN: R41.1; also elsewhere on the board
VSYS: C45.1, L2.2, TP39.1, U10.15 (SYS), U10.16 (SYS)
VUSB: C42.1, R39.1, U10.1 (VAC), U10.24 (VBUS); also elsewhere on the board

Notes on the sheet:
Touch
DAC
IMU
Southbridge
Audio
LED / Wireless
Qwiic
AMP (R)
Buttons
AMP (L)
Display
Battery
HSTX
Joystick
Main board
Pull-ups

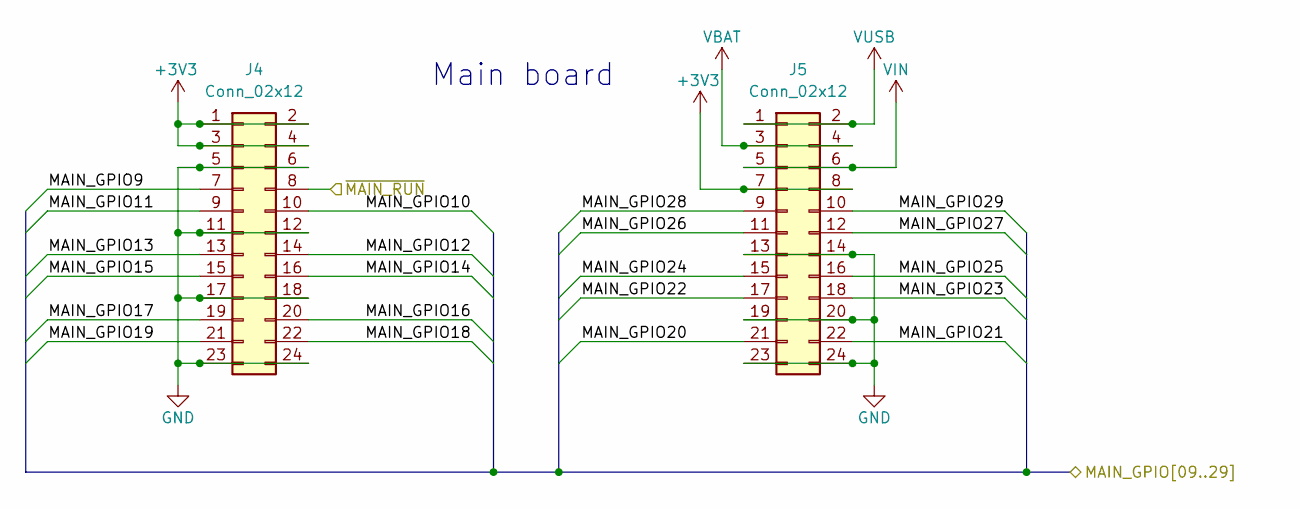
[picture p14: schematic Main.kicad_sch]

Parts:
J4, J5: Conn_02x12; PinHeader_2x12_P2.54mm_Vertical_SMD

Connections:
+3V3: J4.1, J4.2, J4.3, J4.4, J5.7, J5.8; also elsewhere on the board
/Daughterboard/MAIN_GPIO9: J4.7; also elsewhere on the board
/Daughterboard/MAIN_GPIO10: J4.10; also elsewhere on the board
/Daughterboard/MAIN_GPIO11: J4.9; also elsewhere on the board
/Daughterboard/MAIN_GPIO12: J4.14; also elsewhere on the board
/Daughterboard/MAIN_GPIO13: J4.13; also elsewhere on the board
/Daughterboard/MAIN_GPIO14: J4.16; also elsewhere on the board
/Daughterboard/MAIN_GPIO15: J4.15; also elsewhere on the board
/Daughterboard/MAIN_GPIO16: J4.20; also elsewhere on the board
/Daughterboard/MAIN_GPIO17: J4.19; also elsewhere on the board
/Daughterboard/MAIN_GPIO18: J4.22; also elsewhere on the board
/Daughterboard/MAIN_GPIO19: J4.21; also elsewhere on the board
/Daughterboard/MAIN_GPIO20: J5.21; also elsewhere on the board
/Daughterboard/MAIN_GPIO21: J5.22; also elsewhere on the board
/Daughterboard/MAIN_GPIO22: J5.17; also elsewhere on the board
/Daughterboard/MAIN_GPIO23: J5.18; also elsewhere on the board
/Daughterboard/MAIN_GPIO24: J5.15; also elsewhere on the board
/Daughterboard/MAIN_GPIO25: J5.16; also elsewhere on the board
/Daughterboard/MAIN_GPIO26: J5.11; also elsewhere on the board
/Daughterboard/MAIN_GPIO27: J5.12; also elsewhere on the board
/Daughterboard/MAIN_GPIO28: J5.9; also elsewhere on the board
/Daughterboard/MAIN_GPIO29: J5.10; also elsewhere on the board
/Daughterboard/~MAIN_RUN: J4.8; also elsewhere on the board
GND: J4.5, J4.6, J4.11, J4.12, J4.17, J4.18, J4.23, J4.24, J5.13, J5.14, J5.19, J5.20, J5.23, J5.24; also elsewhere on the board
VBAT: J5.3, J5.4; also elsewhere on the board
VIN: J5.5, J5.6; also elsewhere on the board
VUSB: J5.1, J5.2; also elsewhere on the board

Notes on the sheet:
Main board

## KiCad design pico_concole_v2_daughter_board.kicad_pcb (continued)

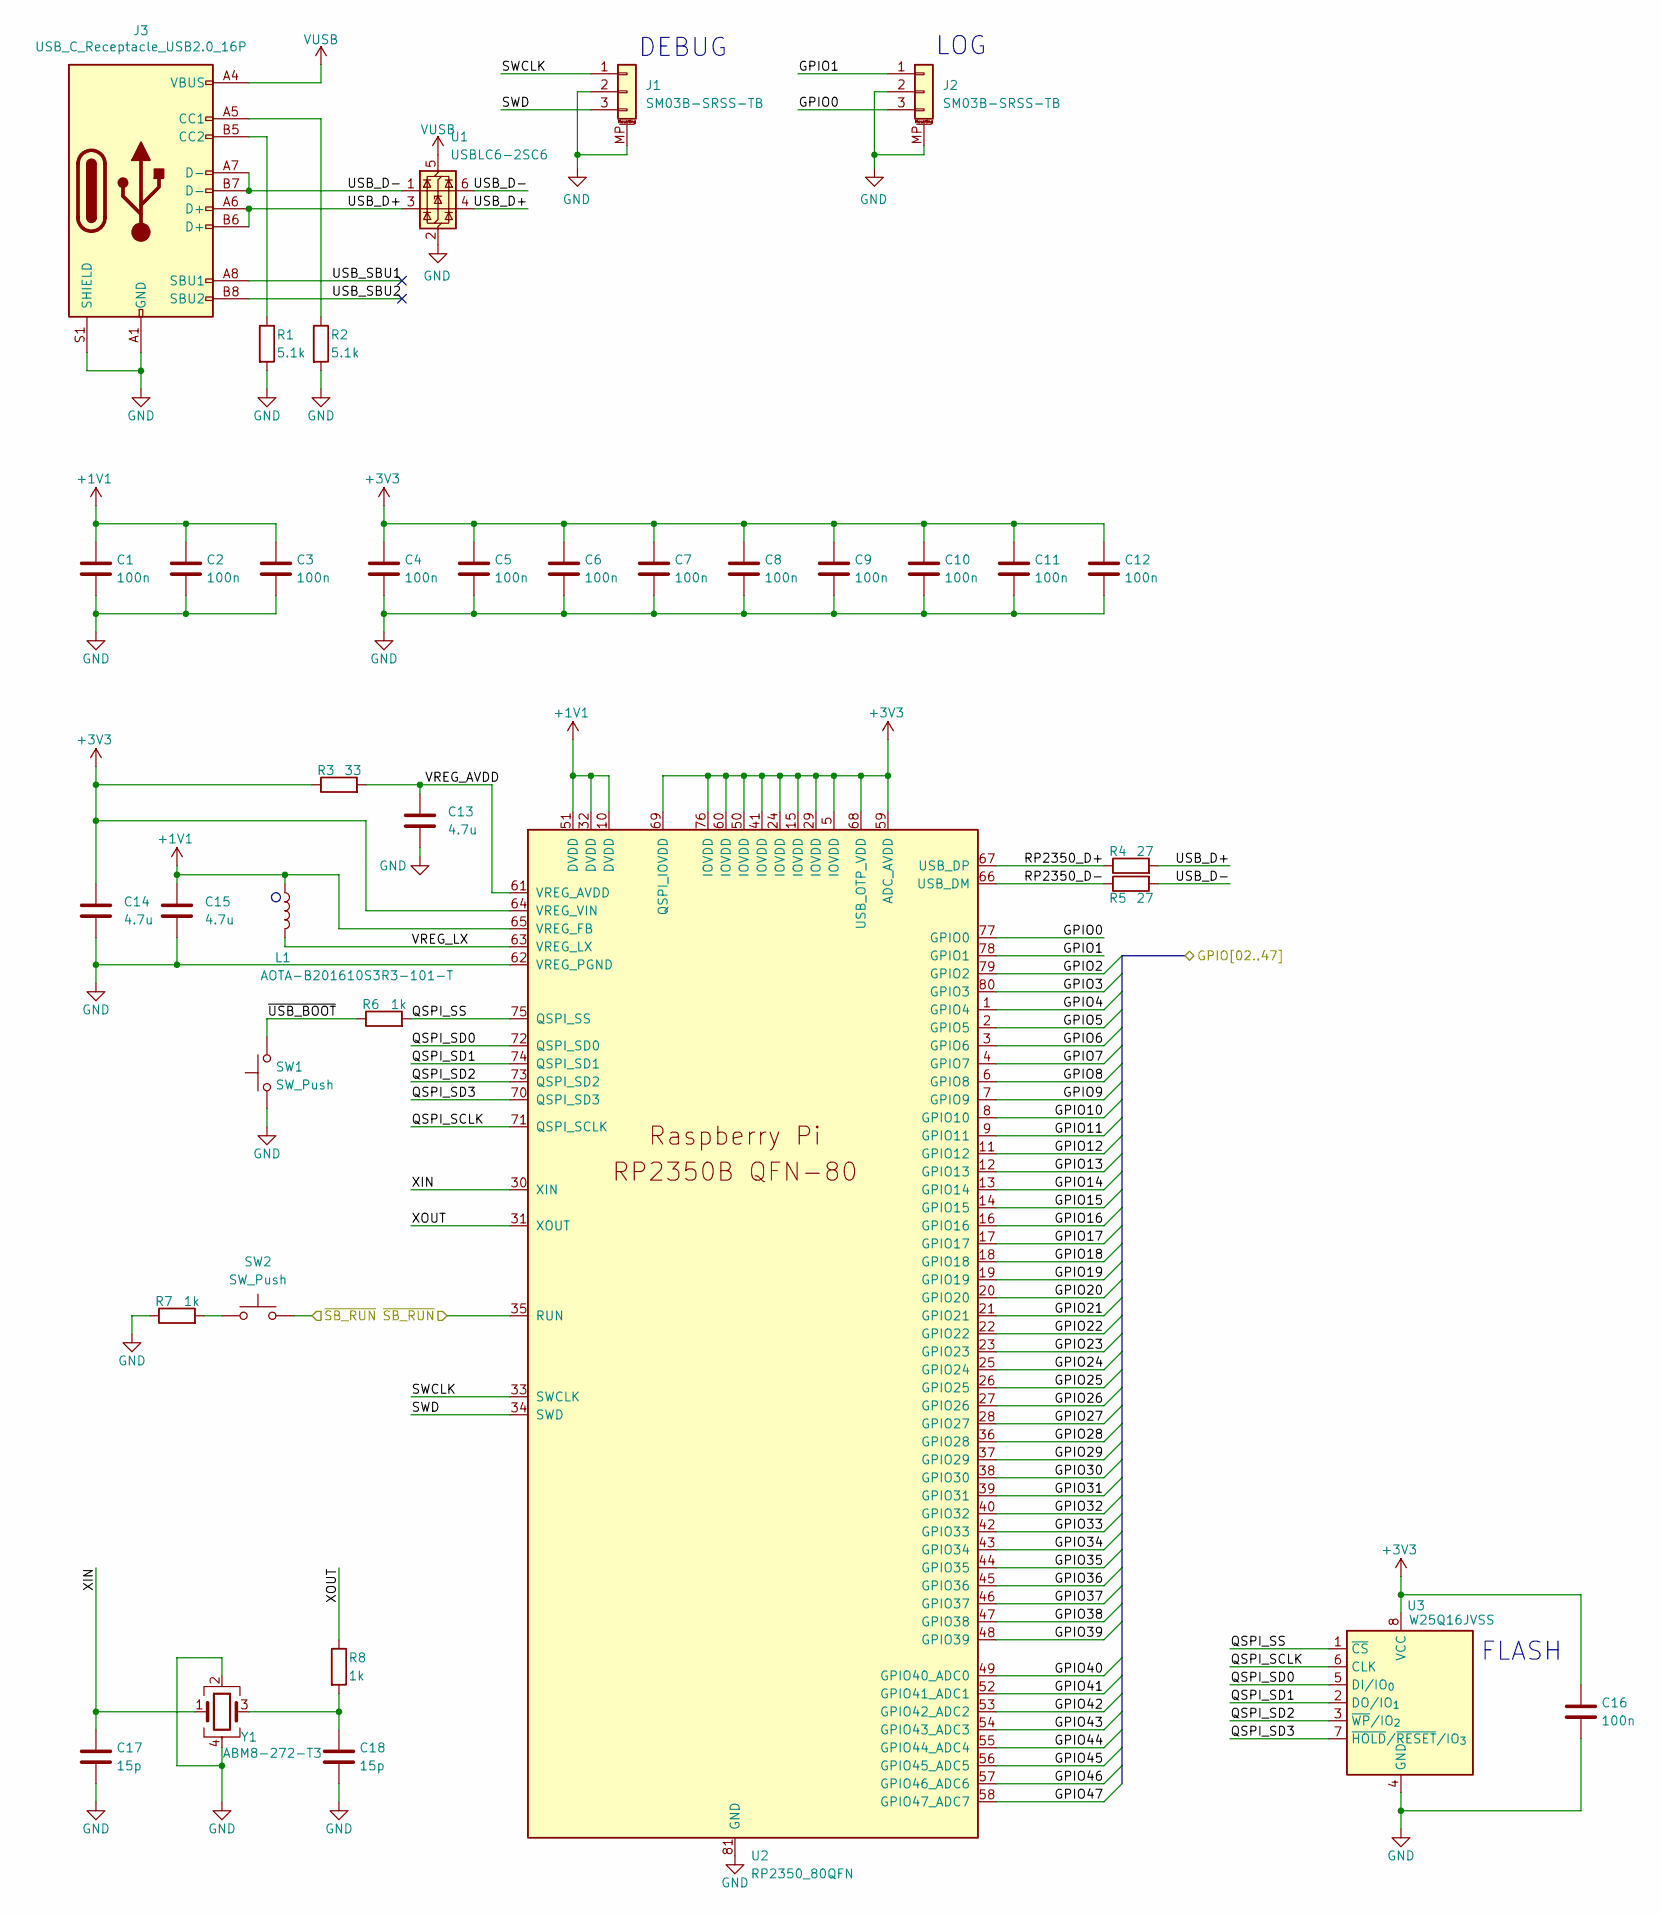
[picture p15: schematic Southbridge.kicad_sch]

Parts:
C1, C2, C3, C4, C5, C6, C7, C8, C9, C10, C11, C12, C16: 100n; C_0402_1005Metric_Pad0.74x0.62mm_HandSolder
C13, C14, C15: 4.7u; C_0603_1608Metric_Pad1.08x0.95mm_HandSolder
C17, C18: 15p; C_0402_1005Metric_Pad0.74x0.62mm_HandSolder
J1, J2: SM03B-SRSS-TB; JST_SH_SM03B-SRSS-TB_1x03-1MP_P1.00mm_Horizontal
J3: USB_C_Receptacle_USB2.0_16P; USB_C_Receptacle_HRO_TYPE-C-31-M-12
L1: AOTA-B201610S3R3-101-T; L_pol_2016
R1, R2: 5.1k; R_0805_2012Metric_Pad1.20x1.40mm_HandSolder
R3: 33; C_0402_1005Metric_Pad0.74x0.62mm_HandSolder
R4, R5: 27; R_0402_1005Metric_Pad0.72x0.64mm_HandSolder
R6, R7, R8: 1k; R_0402_1005Metric_Pad0.72x0.64mm_HandSolder
SW1, SW2: SW_Push; SW_Push_1P1T_NO_Vertical_Wuerth_434133025816
U1: USBLC6-2SC6; SOT-23-6
U2: RP2350_80QFN; QFN-80-1EP_10x10mm_P0.4mm_EP3.4x3.4mm; LCSC PN C42415655
U3: W25Q16JVSS; SOIC-8_5.3x5.3mm_P1.27mm
Y1: ABM8-272-T3; Crystal_SMD_3225-4Pin_3.2x2.5mm; LCSC PN C20625731

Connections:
+1V1: C1.1, C2.1, C3.1, C15.1, L1.1, U2.10 (DVDD), U2.32 (DVDD), U2.51 (DVDD), U2.65 (VREG_FB)
+3V3: C4.1, C5.1, C6.1, C7.1, C8.1, C9.1, C10.1, C11.1, C12.1, C14.1, C16.1, R3.1, U2.5 (IOVDD), U2.15 (IOVDD), U2.24 (IOVDD), U2.29 (IOVDD), U2.41 (IOVDD), U2.50 (IOVDD), U2.59 (ADC_AVDD), U2.60 (IOVDD), U2.64 (VREG_VIN), U2.68 (USB_OTP_VDD), U2.69 (QSPI_IOVDD), U2.76 (IOVDD), U3.8 (VCC); also elsewhere on the board
/Daughterboard/GPIO2: U2.79 (GPIO2); also elsewhere on the board
/Daughterboard/GPIO3: U2.80 (GPIO3); also elsewhere on the board
/Daughterboard/GPIO6: U2.3 (GPIO6); also elsewhere on the board
/Daughterboard/GPIO7: U2.4 (GPIO7); also elsewhere on the board
/Daughterboard/GPIO8: U2.6 (GPIO8); also elsewhere on the board
/Daughterboard/GPIO9: U2.7 (GPIO9); also elsewhere on the board
/Daughterboard/GPIO10: U2.8 (GPIO10); also elsewhere on the board
/Daughterboard/GPIO11: U2.9 (GPIO11); also elsewhere on the board
/Daughterboard/GPIO12: U2.11 (GPIO12); also elsewhere on the board
/Daughterboard/GPIO13: U2.12 (GPIO13); also elsewhere on the board
/Daughterboard/GPIO14: U2.13 (GPIO14); also elsewhere on the board
/Daughterboard/GPIO15: U2.14 (GPIO15); also elsewhere on the board
/Daughterboard/GPIO16: U2.16 (GPIO16); also elsewhere on the board
/Daughterboard/GPIO17: U2.17 (GPIO17); also elsewhere on the board
/Daughterboard/GPIO18: U2.18 (GPIO18); also elsewhere on the board
/Daughterboard/GPIO19: U2.19 (GPIO19); also elsewhere on the board
/Daughterboard/GPIO20: U2.20 (GPIO20); also elsewhere on the board
/Daughterboard/GPIO21: U2.21 (GPIO21); also elsewhere on the board
/Daughterboard/GPIO22: U2.22 (GPIO22); also elsewhere on the board
/Daughterboard/GPIO23: U2.23 (GPIO23); also elsewhere on the board
/Daughterboard/GPIO24: U2.25 (GPIO24); also elsewhere on the board
/Daughterboard/GPIO25: U2.26 (GPIO25); also elsewhere on the board
/Daughterboard/GPIO26: U2.27 (GPIO26); also elsewhere on the board
/Daughterboard/GPIO27: U2.28 (GPIO27); also elsewhere on the board
/Daughterboard/GPIO28: U2.36 (GPIO28); also elsewhere on the board
/Daughterboard/GPIO29: U2.37 (GPIO29); also elsewhere on the board
/Daughterboard/GPIO30: U2.38 (GPIO30); also elsewhere on the board
/Daughterboard/GPIO31: U2.39 (GPIO31); also elsewhere on the board
/Daughterboard/GPIO32: U2.40 (GPIO32); also elsewhere on the board
/Daughterboard/GPIO33: U2.42 (GPIO33); also elsewhere on the board
/Daughterboard/GPIO34: U2.43 (GPIO34); also elsewhere on the board
/Daughterboard/GPIO35: U2.44 (GPIO35); also elsewhere on the board
/Daughterboard/GPIO36: U2.45 (GPIO36); also elsewhere on the board
/Daughterboard/GPIO37: U2.46 (GPIO37); also elsewhere on the board
/Daughterboard/GPIO38: U2.47 (GPIO38); also elsewhere on the board
/Daughterboard/GPIO39: U2.48 (GPIO39); also elsewhere on the board
/Daughterboard/GPIO40: U2.49 (GPIO40_ADC0); also elsewhere on the board
/Daughterboard/GPIO41: U2.52 (GPIO41_ADC1); also elsewhere on the board
/Daughterboard/GPIO42: U2.53 (GPIO42_ADC2); also elsewhere on the board
/Daughterboard/GPIO43: U2.54 (GPIO43_ADC3); also elsewhere on the board
/Daughterboard/GPIO44: U2.55 (GPIO44_ADC4); also elsewhere on the board
/Daughterboard/GPIO45: U2.56 (GPIO45_ADC5); also elsewhere on the board
/Daughterboard/GPIO46: U2.57 (GPIO46_ADC6); also elsewhere on the board
/Daughterboard/GPIO47: U2.58 (GPIO47_ADC7); also elsewhere on the board
/Daughterboard/MAIN_GPIO12: U2.2 (GPIO5); also elsewhere on the board
/Daughterboard/MAIN_GPIO13: U2.1 (GPIO4); also elsewhere on the board
/Daughterboard/~SB_RUN: SW2.2, U2.35 (RUN); also elsewhere on the board
/Southbridge/GPIO0: J2.3, U2.77 (GPIO0)
/Southbridge/GPIO1: J2.1, U2.78 (GPIO1)
/Southbridge/QSPI_SCLK: U2.71 (QSPI_SCLK), U3.6 (CLK)
/Southbridge/QSPI_SD0: U2.72 (QSPI_SD0), U3.5 (DI/IO_{0})
/Southbridge/QSPI_SD1: U2.74 (QSPI_SD1), U3.2 (DO/IO_{1})
/Southbridge/QSPI_SD2: U2.73 (QSPI_SD2), U3.3 (~WP/IO_{2})
/Southbridge/QSPI_SD3: U2.70 (QSPI_SD3), U3.7 (~HOLD/~RESET/IO_{3})
/Southbridge/QSPI_SS: R6.2, U2.75 (QSPI_SS), U3.1 (~CS)
/Southbridge/RP2350_D+: R4.1, U2.67 (USB_DP)
/Southbridge/RP2350_D-: R5.1, U2.66 (USB_DM)
/Southbridge/SWCLK: J1.1, U2.33 (SWCLK)
/Southbridge/SWD: J1.3, U2.34 (SWD)
/Southbridge/USB_D+: J3.A6 (D+), J3.B6 (D+), R4.2, U1.3 (I/O2), U1.4 (I/O2)
/Southbridge/USB_D-: J3.A7 (D-), J3.B7 (D-), R5.2, U1.1 (I/O1), U1.6 (I/O1)
/Southbridge/USB_SBU1: J3.A8 (SBU1)
/Southbridge/USB_SBU2: J3.B8 (SBU2)
/Southbridge/VREG_AVDD: C13.1, R3.2, U2.61 (VREG_AVDD)
/Southbridge/VREG_LX: L1.2, U2.63 (VREG_LX)
/Southbridge/XIN: C17.1, U2.30 (XIN), Y1.1
/Southbridge/XOUT: R8.1, U2.31 (XOUT)
/Southbridge/~USB_BOOT: R6.1, SW1.2
GND: C1.2, C2.2, C3.2, C4.2, C5.2, C6.2, C7.2, C8.2, C9.2, C10.2, C11.2, C12.2, C13.2, C14.2, C15.2, C16.2, C17.2, C18.2, J1.2, J1.MP (MountPin), J2.2, J2.MP (MountPin), J3.A1 (GND), J3.A12 (GND), J3.B1 (GND), J3.B12 (GND), J3.S1 (SHIELD), R1.2, R2.2, R7.1, SW1.1, U1.2 (GND), U2.62 (VREG_PGND), U2.81 (GND), U3.4 (GND), Y1.2, Y1.4; also elsewhere on the board
unnamed: C18.1, R8.2, Y1.3
unnamed: J3.A5 (CC1), R2.1
unnamed: J3.B5 (CC2), R1.1
unnamed: R7.2, SW2.1
VUSB: J3.A4 (VBUS), J3.A9 (VBUS), J3.B4 (VBUS), J3.B9 (VBUS), U1.5 (VBUS); also elsewhere on the board

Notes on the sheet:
LOG
DEBUG
FLASH

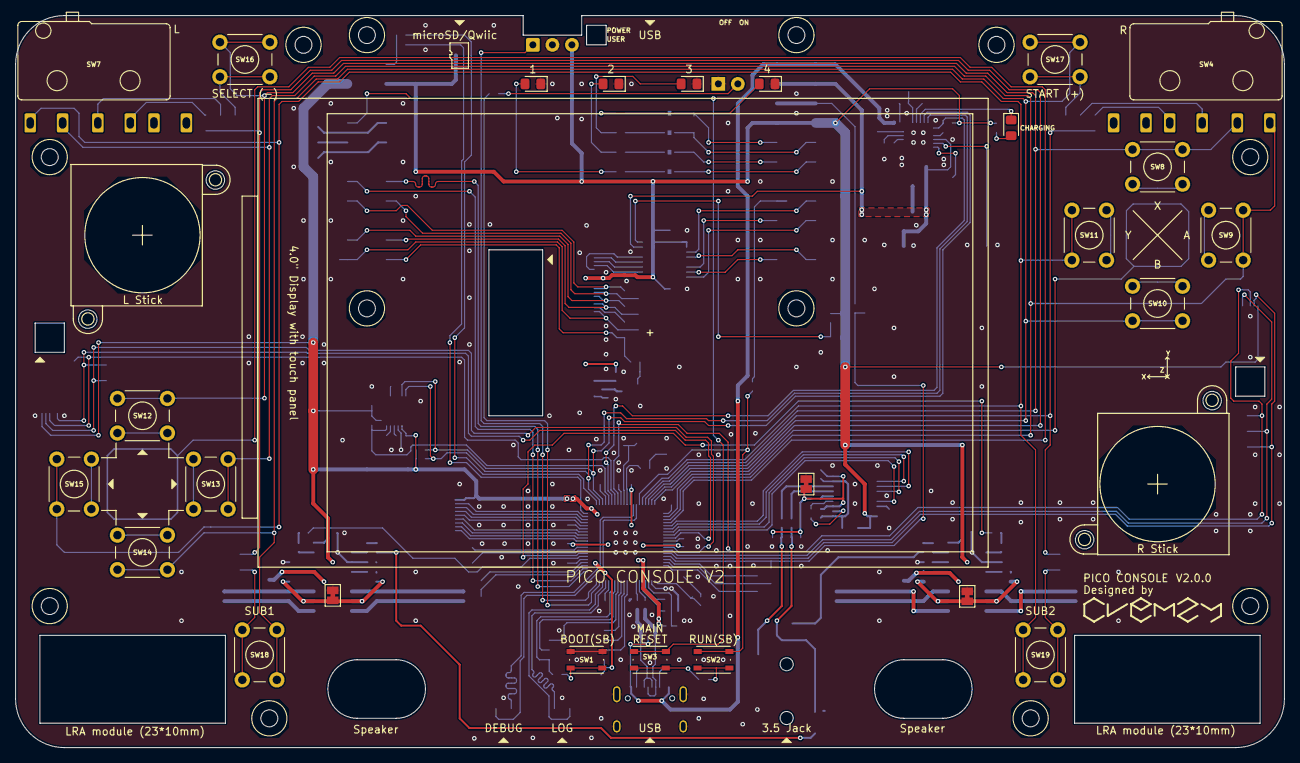
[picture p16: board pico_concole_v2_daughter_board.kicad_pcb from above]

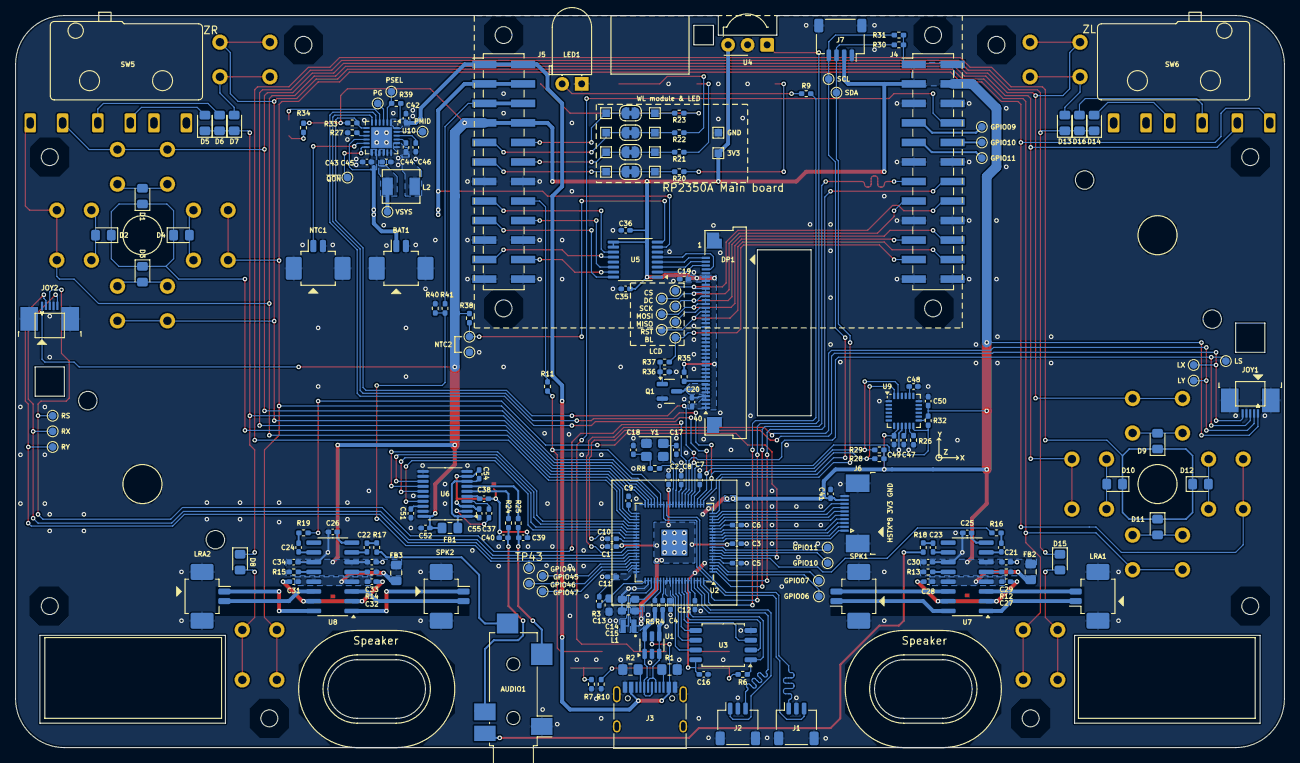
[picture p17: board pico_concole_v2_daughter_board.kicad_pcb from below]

Board: 2 copper layers, 165.1 x 95.2 mm, 232 parts (195 on the bottom side), 180 nets.

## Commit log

2026-04-11 V2.0.0 WIP
    [Daughterboard.kicad_sch, Main.kicad_sch, Southbridge.kicad_sch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]
2026-04-12 Add switch footprint
2026-04-12 Place components temporarily
    [Daughterboard.kicad_sch, Main.kicad_sch, pico_concole_v2_daughter_board.kicad_pcb]
2026-04-21 Add footprint
2026-04-24 Remove unused footprint
2026-04-25 Update LCD pin assignments
    [Daughterboard.kicad_sch, pico_concole_v2_daughter_board.kicad_pcb]
2026-05-03 routing complete
    [Daughterboard.kicad_sch, pico_concole_v2_daughter_board.kicad_pcb]
2026-05-03 Update BOM
    [Daughterboard.kicad_sch, Southbridge.kicad_sch, pico_concole_v2_daughter_board.kicad_pcb]
2026-05-04 Update schematic - Change L2 - Add NTC2 pad - Connect pins to measure voltages
    [Daughterboard.kicad_sch, pico_concole_v2_daughter_board.kicad_pcb]
